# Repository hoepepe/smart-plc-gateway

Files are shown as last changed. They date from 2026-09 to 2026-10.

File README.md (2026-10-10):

# Smart PLC Gateway

Thiết bị giá rẻ đọc dữ liệu từ máy PLC đời cũ — trạng thái máy, lực ép, lực xiết, áp lực khí nén — để tính OEE theo thời gian thực và phát hiện chu kỳ gia công bất thường. Không đụng vào máy: nguồn điện riêng, chỉ đọc, không sửa chương trình PLC.

> Bài dự thi **DENSO Factory Hacks 2026 — đề D1** (Kết nối PLC–IPC giá rẻ để thu dữ liệu).

---

## Bài toán

Theo trả lời của mentor DENSO ngày 21/09/2026:

- DENSO **đã có danh sách tín hiệu** và muốn lấy dữ liệu **trực tiếp từ PLC**
- Hiện dữ liệu PLC đời cũ được lấy **bằng tay qua thẻ nhớ**, và máy cũ **chưa được đưa lên hệ thống giám sát**
- Bộ mở rộng truyền thông cho PLC tốn **khoảng 30 triệu mỗi máy**, chưa tính công và layout
- Ba dòng PLC đang dùng nhiều: **Keyence KV-8000**, **Omron CJ2M-CPU33 và CPM2C**, **Mitsubishi Q10UDEHCPU**
- Điều kiện gia công cần thu: áp lực khí nén, chiều cao, tải trọng, lực ép, lực xiết
- Trạng thái máy: dừng, chuẩn bị vận hành, auto running, đang làm việc, hoàn thành, báo lỗi
- Thiết bị thêm vào phải dùng **nguồn ngoài**, và nên **đi dây** trước để ổn định

Gateway đọc các thanh ghi đó theo giao thức gốc của từng hãng, rồi làm hai việc:
1. **Trạng thái máy → OEE**: độ sẵn sàng, hiệu suất, chất lượng, và nguyên nhân dừng máy xếp theo thời gian mất
2. **Chu kỳ gia công → cảnh báo chất lượng**: chu kỳ ép hoặc siết có hình dạng lạ thường đi kèm chi tiết lỗi

---

## Cấu trúc

```
src/                     Giao diện (React + TypeScript + Vite)
  App.tsx                Điều phối mô phỏng, MQTT và bốn màn hình
  data/machines.ts       Cấu hình 4 máy — PLC, giao thức, thanh ghi, mã lỗi
  data/cycles.json       Tham số mô hình, xuất từ ml/cycles.py
  utils/detector.ts      Khoảng cách Mahalanobis — đúng mô hình đã đánh giá
  utils/oee.ts           OEE = sẵn sàng × hiệu suất × chất lượng
  utils/sim.ts           Mô phỏng vận hành khi chưa có PLC thật
  utils/mqtt.ts          Nối broker, tự về chế độ mô phỏng sau 3 giây
  components/            MonitorTab, OeeTab, DetectionTab, ConnectTab

ml/
  cycles.py              Sinh chu kỳ gia công, huấn luyện và đánh giá, xuất cycles.json
  gateway_sim.py         Giả lập gateway, phát MQTT đúng schema của gateway thật
  legacy_nhan_dien_tin_hieu/   Hướng cũ: AI đoán dây — xem README trong đó

edge/                    AI tự học tại chỗ: runtime nhiều máy, học → duyệt → giám sát, phiên bản, phản hồi
  runtime.py             python -m edge.runtime — đọc PLC/mô phỏng, chấm điểm, MQTT gw/{gw}/...
  learner.py detector.py quality.py store.py config.py sources.py

backend/
  main.py                Nhận MQTT → SQLite → REST API, tính OEE và nguyên nhân dừng máy
```

## Luồng dữ liệu

```
PLC (Keyence / Omron / Mitsubishi)
   │  giao thức gốc của hãng, CHỈ ĐỌC
   ▼
Gateway ── tính đặc trưng chu kỳ, chấm điểm bất thường tại chỗ
   │  MQTT  gw/01/m/{máy}/state   gw/01/m/{máy}/cycle
   ▼
Broker MQTT (Mosquitto, trong mạng nội bộ)
   ├── WebSocket 9001 ──► giao diện
   └── TCP 1883 ────────► backend/main.py ──► SQLite ──► REST API :8000
```

---

## Chạy thử

### Giao diện

```bash
npm install
npm run dev
```

Mở `http://localhost:3000`. Không có broker thì giao diện tự chạy chế độ mô phỏng.

### Mô hình phát hiện chu kỳ bất thường

```bash
cd ml
pip install numpy scikit-learn
python cycles.py
cp cycles.json ../src/data/cycles.json
```

### Chạy đủ chuỗi: broker → gateway giả lập → máy chủ → giao diện

Cài Mosquitto, thêm vào `mosquitto.conf` — **phải bật cả cổng WebSocket**, nếu không trình duyệt không nối được:

```
listener 1883
protocol mqtt

listener 9001
protocol websockets

allow_anonymous true
```

Rồi mở ba cửa sổ dòng lệnh:

```bash
mosquitto -c mosquitto.conf                     # 1. broker
cd backend && pip install -r requirements.txt && python main.py   # 2. máy chủ
cd ml && pip install paho-mqtt && python gateway_sim.py            # 3. gateway giả lập
```

Mở giao diện: góc trên đổi thành **Đã nối gateway**. API máy chủ xem tại `http://localhost:8000/docs`.

| Endpoint | Công dụng |
|---|---|
| `GET /api/health` | Máy chủ sống chưa, đã nối MQTT chưa, đã nhận bao nhiêu bản tin |
| `GET /api/machines` | Trạng thái hiện tại và OEE từng máy |
| `GET /api/machines/{id}/states` | Lịch sử trạng thái |
| `GET /api/machines/{id}/cycles` | Chu kỳ gần đây, lọc được chu kỳ bất thường |
| `GET /api/machines/{id}/oee` | OEE một máy |
| `GET /api/stops` | Nguyên nhân dừng máy, xếp theo thời gian mất |

### AI tự học tại chỗ cho từng máy (tab "Máy và AI tự học")

Mỗi máy tự học chuẩn bình thường của chính nó ngay trên gateway, kỹ sư duyệt rồi mới giám sát, bấm phản hồi trên từng cảnh báo để AI học tiếp. Chi tiết: [docs/HuongDan_AI_TuHoc.md](docs/HuongDan_AI_TuHoc.md).

```bash
pip install -r edge/requirements.txt
python -m edge.runtime --demo                      # 4 máy mô phỏng (ép, siết, CNC, khí nén)
python -m edge.runtime --add-plc 192.168.1.39:3000 # PLC Mitsubishi thật, chỉ đọc
npm run dev                                         # mở tab "Máy và AI tự học"
python -m pytest tests/test_edge.py                 # 6 bài kiểm thử vòng đời
```

---

## Kết quả đo được

Đo trên chu kỳ **mô phỏng**, tách theo ca làm việc: 20 ca để học, 6 ca để chọn ngưỡng, 6 ca để kiểm tra — không ca nào dùng chung. Chỉ học trên chu kỳ bình thường, vì nhà máy có rất ít dữ liệu lỗi.

| Đại lượng | Bắt lỗi trung bình | Báo động giả |
|---|---|---|
| Lực ép | 99,4% | 0,7% |
| Lực xiết | 100% | 0,7% |
| Áp lực khí nén | 70,6% | 0% |

**Chỗ còn yếu:** van kẹt chỉ bắt được 33%, nguồn khí yếu 78%. Giao diện ghi rõ giả thuyết nguyên nhân và hướng sửa cho từng dạng.

**Vì sao chọn khoảng cách Mahalanobis thay vì Isolation Forest:** trên 9 dạng lỗi, Mahalanobis bắt tốt hơn ở 5 dạng, ngang ở 2, kém ở 2. Nó chỉ cần một vector và một ma trận 9×9 nên chạy được trên ESP32, và chỉ ra được đặc trưng nào lệch — kỹ sư biết vì sao máy bị cảnh báo.

**Chất lượng trong OEE là ước tính** — nó đếm chu kỳ bị gắn cờ, mà chu kỳ bất thường mới là nghi lỗi. Nối kết quả kiểm tra QC sẽ chính xác hơn.

---

## Những điều chưa biết

- **Vì sao cần bộ mở rộng 30 triệu khi cả ba CPU đã có cổng Ethernet?** Nếu cổng đang bận cho HMI, gateway cũng phải thêm phần cứng. Cần hỏi mentor trước khi dùng con số tiết kiệm.
- **Thẻ nhớ được rút bao lâu một lần?** Đây là vế "trước" của phép đo độ trễ dữ liệu.
- **Giao thức và lệnh đọc từng dòng PLC** trong `machines.ts` cần đối chiếu manual của hãng.
- Chưa có PLC thật để thử. Toàn bộ trạng thái máy là mô phỏng.

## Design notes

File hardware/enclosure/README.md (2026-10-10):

# Vỏ hộp Smart PLC Gateway (in 3D)

| File | Dùng để |
|---|---|
| `out/gateway_base.stl` | Đế hộp — in thẳng, miệng hộp hướng lên, không cần support |
| `out/gateway_lid_print.stl` | Nắp — đã lật sẵn để mặt ngoài nằm trên bàn in |
| `out/gateway_lid.stl` | Nắp ở tư thế lắp (để xem/ghép trong CAD) |
| `out/viewer.html` | Trình xem 3D xoay được (mở bằng trình duyệt, cần mạng để tải Three.js) |
| `gen_enclosure.py` | Mã tạo hình — mọi kích thước nằm ở các bảng đầu file |

Kích thước ngoài 165 × 110 × 60,5 mm (+ 2 tai bắt vít 12 mm hai đầu). Vừa bàn in 220 × 220.

**Trước khi in:** đo module thật bằng thước kẹp, sửa bảng `MODULES`, `CUTS`, `OLED`, rồi chạy
`python gen_enclosure.py && python build_viewer.py`.

Vật tư kèm theo: 4 vít M3×10 tự ren (nắp), 4 vít M2×6 (OLED), 3 ốc siết cáp PG7, jack DC cái bắt panel ren M8,
2 LED 5 mm, (tuỳ chọn) kẹp DIN rail 35 mm bắt 2 vít M3 dưới đáy.

In: PETG (chịu nhiệt tốt hơn PLA trong tủ điện), lớp 0,2 mm, 3 vách, infill 20%.

**Chỗ cho dây dupont (bản demo):** module có header hàn sẵn hướng xuống (ESP32, W5500, RS232, PC817, HW-685)
được kê cao 28 mm để đầu dupont cái (14 mm) và chỗ uốn dây nằm gọn bên dưới. ADS1115 và MPU6050 thường bán
kèm header rời: hàn header **hướng lên**, module kê thấp 6 mm, dây đi phía trên. Đổi trong bảng `MODULES` (DOWN/UP).

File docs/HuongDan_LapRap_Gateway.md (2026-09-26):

# Hướng dẫn lắp ráp Smart PLC Gateway

*Từ linh kiện rời đến thiết bị hoàn chỉnh trong vỏ ray DIN — DENSO Factory Hacks 2026, đề D1*

---

## Đọc trước khi bắt đầu

**Nguyên tắc số một: lắp từng khối, thử từng khối.** Không hàn tất cả rồi mới cắm điện. Mỗi bước dưới đây kết thúc bằng một phép thử — chỉ sang bước sau khi phép thử đạt. Lắp một lèo rồi hỏng thì không biết hỏng ở đâu.

**Ba điều có thể làm cháy linh kiện ngay lập tức:**

1. Nối ESP32 vào LM2596 **trước khi** chỉnh đầu ra về 5V. LM2596 xuất xưởng có thể ra gần bằng điện áp vào — 24V vào chân VIN là ESP32 chết ngay.
2. Đưa điện áp trên 3,3V vào bất kỳ chân GPIO nào của ESP32. Chân GPIO không chịu 5V.
3. Đấu ngược cực nguồn 24V. Luôn đo bằng đồng hồ trước khi cắm.

**Luôn rút nguồn khi đấu dây.** Chỉ cắm lại khi đã kiểm tra xong.

---

## Phần 1 — Linh kiện

### Linh kiện chính (tổng khoảng 770.000đ)

| # | Linh kiện | Số lượng | Vai trò | Giá |
|---|---|---|---|---|
| 1 | ESP32 DevKit V1 (38 chân) | 1 | Bộ xử lý | 100.000 |
| 2 | Module Ethernet W5500 | 1 | Nối cổng Ethernet của PLC | 90.000 |
| 3 | Module MAX485 | 1 | Cổng RS485 (Keyence KV-8000) | 30.000 |
| 4 | Module MAX3232 | 1 | Cổng RS-232C (Omron CPM2C) | 25.000 |
| 5 | Module ADS1115 | 1 | Đọc tín hiệu analog | 70.000 |
| 6 | Module hạ áp 0–10V → 0–3,3V | 1 | Chuẩn hóa tín hiệu 0–10V | 50.000 |
| 7 | Điện trở **150Ω, sai số 0,1%** | 2 | Đọc tín hiệu 4–20mA | 10.000 |
| 8 | Module PC817 cách ly 4 kênh | 1 | Đọc cờ trạng thái 24V | 40.000 |
| 9 | Adapter 24V DC, 2A | 1 | Nguồn riêng, không lấy từ máy | 120.000 |
| 10 | Module LM2596 (hạ áp chỉnh được) | 1 | 24V → 5V | 30.000 |
| 11 | OLED 0,96" SSD1306 I2C | 1 | Hiện trạng thái tại chỗ | 45.000 |
| 12 | Vỏ ray DIN, domino, PCB lỗ, dây, jack DC | 1 bộ | Đóng gói | 160.000 |

### Linh kiện phụ (thường có sẵn hoặc vài nghìn đồng)

- Điện trở 10kΩ và 20kΩ — cầu chia áp cho chân RO của MAX485
- Header cái 2,54mm — cắm module lên PCB, tháo ra được khi hỏng
- Dây cáp mạng RJ45 ngắn
- Ống co nhiệt, băng keo cách điện

### Linh kiện chỉ dùng khi demo trên bàn

Biến trở 10kΩ, nút nhấn, MPU6050 — tạo tín hiệu giả khi chưa có máy thật. Không nằm trong thiết bị cuối.

### Dụng cụ

- Mỏ hàn (khuyên dùng loại chỉnh nhiệt), thiếc hàn có nhựa thông
- **Đồng hồ vạn năng** — bắt buộc, dùng ở gần như mọi bước
- Kìm tuốt dây, kìm cắt, tua vít nhỏ đầu dẹt và đầu bake
- Breadboard và dây cắm (để thử trước khi hàn)
- Cáp USB micro-B có truyền dữ liệu (không phải cáp chỉ sạc)

---

## ⚠️ Ba chỗ BOM cũ bị sai — đã sửa trong bảng trên

Nếu Đạt đã mua theo danh sách cũ, cần điều chỉnh:

**1. Điện trở 4–20mA phải là 150Ω, không phải 250Ω.**
Dòng 20mA qua 250Ω tạo ra 5V, trong khi ADS1115 cấp 3,3V chỉ chịu tối đa khoảng 3,6V ở đầu vào. Với 150Ω: 4mA → 0,6V, 20mA → 3,0V, nằm gọn trong dải. *Đây là lỗi trong lời khuyên trước đó của mình.*

**2. MAX485 cần cầu chia áp ở chân RO.**
MAX485 chạy ở 5V nên chân RO xuất ra khoảng 5V — đưa thẳng vào ESP32 sẽ hỏng chân. Thêm cầu chia 10kΩ/20kΩ hạ về 3,3V. Nếu mua mới, chọn **MAX3485** (bản 3,3V) thì không cần cầu chia.

**3. Omron CPM2C cần MAX3232, không phải MAX485.**
CPM2C dùng cổng RS-232C. RS-232 dùng mức điện áp khoảng ±12V, hoàn toàn khác RS-485. MAX485 không nói chuyện được với RS-232. Cần mua thêm module MAX3232 (khoảng 25.000đ). *Cũng là lỗi trong lời khuyên trước đó.*

---

## Phần 2 — Sơ đồ tổng quát

```
                    ┌─────────────────────────────────────────┐
  Adapter 24V ──────┤ LM2596 ──5V──┬── ESP32 (VIN)             │
                    │              └── MAX485 (VCC)            │
                    │                                          │
                    │  ESP32 3V3 ──┬── W5500                   │
                    │              ├── ADS1115                 │
                    │              ├── OLED                    │
                    │              ├── MAX3232                 │
                    │              └── PC817 (phía ESP32)      │
                    │                                          │
   PLC Ethernet ────┤ W5500 ──SPI──── ESP32                    │
   PLC RS485 ───────┤ MAX485 ─UART2── ESP32                    │
   PLC RS-232C ─────┤ MAX3232 ─UART1─ ESP32                    │
   Cảm biến 0–10V ──┤ Hạ áp ──┐                                │
   Cảm biến 4–20mA ─┤ 150Ω ───┼─ ADS1115 ─I2C── ESP32          │
   Cờ trạng thái 24V┤ PC817 (cách ly) ──── ESP32 GPIO          │
                    └─────────────────────────────────────────┘
```

### Bảng gán chân ESP32 — dán lên bàn làm việc

| Chân ESP32 | Nối tới | Ghi chú |
|---|---|---|
| VIN | LM2596 OUT+ (5V) | Chỉ cấp 5V |
| GND | GND chung | Trừ phía hiện trường của PC817 |
| 3V3 | VCC các module 3,3V | |
| GPIO 21 | SDA — ADS1115 và OLED | Dùng chung bus I2C |
| GPIO 22 | SCL — ADS1115 và OLED | |
| GPIO 18 | W5500 SCK | SPI |
| GPIO 19 | W5500 MISO | |
| GPIO 23 | W5500 MOSI | |
| GPIO 5 | W5500 CS | |
| GPIO 26 | W5500 RST | Không bắt buộc |
| GPIO 17 | MAX485 DI | UART2 TX |
| GPIO 16 | MAX485 RO **qua cầu chia áp** | UART2 RX |
| GPIO 25 | MAX485 DE + RE (nối chung) | Chọn chiều truyền |
| GPIO 32 | MAX3232 T1IN | UART1 TX |
| GPIO 33 | MAX3232 R1OUT | UART1 RX |
| GPIO 34, 35, 36, 39 | 4 đầu ra PC817 | Chân chỉ-nhập, không có pull-up trong |

**Không dùng** GPIO 0, 2, 12, 15 — đây là chân quyết định chế độ khởi động của ESP32, nối linh kiện vào dễ làm chip không boot được.

### Địa chỉ I2C

| Thiết bị | Địa chỉ | Cách đặt |
|---|---|---|
| ADS1115 | 0x48 | Chân ADDR nối GND |
| OLED SSD1306 | 0x3C | Mặc định |

Hai địa chỉ khác nhau nên dùng chung một bus được.

---

## Phần 3 — Lắp từng khối trên breadboard

### Bước 1: Khối nguồn

**Chưa cắm ESP32 vào ở bước này.**

1. Đấu adapter 24V vào LM2596: dây dương vào `IN+`, dây âm vào `IN-`. Dùng jack DC cái để sau này tháo ra dễ.
2. Cắm adapter.
3. Đặt đồng hồ ở thang DC 20V, đo giữa `OUT+` và `OUT-`.
4. Vặn biến trở trên LM2596 (thường là con ốc nhỏ màu xanh dương) cho đến khi đồng hồ chỉ **5,0V**. Vặn nhiều vòng mới thấy thay đổi — bình thường.
5. Rút adapter, cắm lại, đo lần nữa cho chắc vẫn là 5,0V.

**Kiểm tra đạt:** đầu ra ổn định 4,9–5,1V qua nhiều lần cắm rút.

> Nếu không chỉnh được xuống dưới vài vôn: LM2596 có thể là bản đầu ra cố định. Kiểm tra lại loại module.

### Bước 2: ESP32 chạy một mình

1. Cắm ESP32 vào máy tính bằng cáp USB (chưa nối LM2596).
2. Cài Arduino IDE, thêm board ESP32 (Boards Manager → tìm "esp32" của Espressif).
3. Chọn board **"ESP32 Dev Module"**, nạp chương trình thử:

```cpp
void setup() {
  Serial.begin(115200);
  pinMode(2, OUTPUT);  // LED xanh trên board
}
void loop() {
  digitalWrite(2, !digitalRead(2));
  Serial.println("ESP32 dang chay");
  delay(500);
}
```

**Kiểm tra đạt:** LED trên board nhấp nháy, Serial Monitor in ra dòng chữ.

> Không nạp được: giữ nút **BOOT** trên board khi IDE hiện "Connecting...". Vẫn không được: đổi cáp USB — nhiều cáp chỉ sạc, không truyền dữ liệu.

### Bước 3: Cấp nguồn ESP32 từ LM2596

1. Rút USB. Rút adapter.
2. Nối `OUT+` của LM2596 → chân **VIN** của ESP32. `OUT-` → **GND**.
3. Cắm adapter. LED nguồn trên ESP32 phải sáng, LED chương trình nhấp nháy như bước 2.
4. Đo chân **3V3** của ESP32 so với GND: phải ra khoảng 3,3V.

**Kiểm tra đạt:** ESP32 chạy bằng nguồn 24V qua LM2596, chân 3V3 đúng 3,3V.

> **Lưu ý khi nạp code sau này:** rút dây VIN khỏi LM2596 trước khi cắm USB. Tránh cấp hai nguồn 5V cùng lúc vào một board — nhiều bản ESP32 giá rẻ không có diode chống ngược.

### Bước 4: Bus I2C — OLED trước, ADS1115 sau

**4a. OLED**

| OLED | ESP32 |
|---|---|
| VCC | 3V3 |
| GND | GND |
| SDA | GPIO 21 |
| SCL | GPIO 22 |

Nạp chương trình quét I2C:

```cpp
#include <Wire.h>
void setup() {
  Serial.begin(115200);
  Wire.begin(21, 22);
  for (byte a = 1; a < 127; a++) {
    Wire.beginTransmission(a);
    if (Wire.endTransmission() == 0) Serial.printf("Tim thay: 0x%02X\n", a);
  }
}
void loop() {}
```

**Kiểm tra đạt:** in ra `0x3C`.

**4b. Thêm ADS1115 vào cùng bus**

| ADS1115 | ESP32 |
|---|---|
| VDD | 3V3 |
| GND | GND |
| SDA | GPIO 21 (chung với OLED) |
| SCL | GPIO 22 (chung với OLED) |
| ADDR | GND |

Chạy lại chương trình quét.

**Kiểm tra đạt:** in ra **cả hai** `0x3C` và `0x48`. Thiếu cái nào thì kiểm tra lại dây cái đó.

### Bước 5: Đầu vào analog

Làm theo thứ tự từ an toàn đến nguy hiểm dần.

**5a. Thử bằng biến trở (an toàn nhất)**

Biến trở 10kΩ: một đầu vào 3V3, một đầu vào GND, chân giữa vào `A0` của ADS1115. Cài thư viện **Adafruit ADS1X15**, đọc kênh 0 rồi vặn biến trở.

**Kiểm tra đạt:** giá trị đọc thay đổi mượt từ 0 đến khoảng 3,3V theo vòng vặn.

**5b. Tín hiệu 0–10V**

Tín hiệu 0–10V **không bao giờ** được đưa thẳng vào ADS1115. Luôn đi qua module hạ áp:

```
Cảm biến 0–10V ──► [Module hạ áp] ──► 0–3,3V ──► ADS1115 A1
```

Trước khi nối vào ADS1115: cấp 10V vào đầu vào module, đo đầu ra bằng đồng hồ, phải **không quá 3,3V**.

**5c. Tín hiệu 4–20mA**

Điện trở 150Ω mắc nối tiếp trong vòng dòng, đo điện áp rơi trên nó:

```
+24V ──► Cảm biến 4–20mA ──► ┬── ADS1115 A2
                              │
                           [150Ω]
                              │
                             GND
```

Dòng 4mA cho 0,6V, 20mA cho 3,0V. Phần mềm đổi ngược: `dong_mA = dien_ap / 150 * 1000`.

> Cách mắc này nối đất của vòng cảm biến với đất của gateway — chấp nhận được khi demo. Khi lắp trong nhà máy, cân nhắc bộ cách ly tín hiệu analog để tránh vòng lặp đất.

### Bước 6: Đầu vào số 24V qua PC817 — điểm cách ly quan trọng nhất

Module PC817 có **hai phía tách biệt về điện**. Đây là toàn bộ lý do dùng nó.

| Phía hiện trường (máy) | Phía ESP32 |
|---|---|
| IN1–IN4: tín hiệu 24V từ máy | OUT1–OUT4 → GPIO 34, 35, 36, 39 |
| GND hiện trường: đất của tín hiệu 24V | VCC → 3V3, GND → GND của ESP32 |

**Tuyệt đối không nối GND hiện trường với GND của ESP32.** Nối vào là mất cách ly, và sự cố điện phía máy có thể truyền sang gateway.

Kiểm tra module trước khi dùng: xem điện trở ở phía đầu vào có phù hợp mức 24V không (module ghi 12–24V là được). Loại chỉ ghi 3,3–5V dùng với 24V sẽ cháy LED bên trong.

**Kiểm tra đạt:** dùng adapter 24V riêng và một nút nhấn làm "cờ trạng thái giả". Nhấn nút, GPIO tương ứng đổi mức; nhả ra, đổi lại.

### Bước 7: Ethernet W5500

| W5500 | ESP32 |
|---|---|
| VCC | 3V3 (kiểm tra module của bạn — một số loại có chân 5V riêng) |
| GND | GND |
| SCK | GPIO 18 |
| MISO | GPIO 19 |
| MOSI | GPIO 23 |
| CS (hoặc SS/SCS) | GPIO 5 |
| RST | GPIO 26 |

Cắm dây mạng từ W5500 vào router hoặc thẳng vào laptop. Dùng thư viện **Ethernet** của Arduino, gọi `Ethernet.init(5)` trước `Ethernet.begin()`.

**Kiểm tra đạt:** ESP32 nhận được địa chỉ IP (in ra Serial), và từ máy tính `ping` được tới địa chỉ đó.

> Tắt WiFi trong firmware (`WiFi.mode(WIFI_OFF)`). Vừa đúng khuyến nghị đi dây của DENSO, vừa giảm tải cho bộ ổn áp 3,3V trên ESP32 đang phải nuôi cả W5500.

Sau khi ping được, thử gửi một bản tin MQTT tới broker Mosquitto trên laptop bằng thư viện **PubSubClient**, topic `gw/01/status`. Mở dashboard, thấy nhận được là đạt.

### Bước 8: Cổng serial — RS485 và RS-232C

**8a. MAX485 cho Keyence KV-8000**

| MAX485 | ESP32 |
|---|---|
| VCC | 5V (từ LM2596) |
| GND | GND |
| DI | GPIO 17 |
| RO | GPIO 16 **qua cầu chia áp** |
| DE + RE | Nối chung với nhau → GPIO 25 |
| A, B | Nối vào cổng RS485 của PLC |

Cầu chia áp cho chân RO — **bắt buộc**:

```
MAX485 RO ──[10kΩ]──┬──► GPIO 16
                    │
                 [20kΩ]
                    │
                   GND
```

Trước khi nối GPIO 16: cấp nguồn, đo điểm giữa cầu chia khi đường truyền rảnh — phải khoảng **3,3V, không phải 5V**.

**8b. MAX3232 cho Omron CPM2C**

| MAX3232 | ESP32 |
|---|---|
| VCC | 3V3 |
| GND | GND |
| T1IN (TXD) | GPIO 32 |
| R1OUT (RXD) | GPIO 33 |
| Cổng DB9 | Nối vào cổng RS-232C của PLC |

MAX3232 chạy tốt ở 3,3V nên không cần cầu chia.

**Kiểm tra đạt (cả hai):** thử vòng lặp — nối chân phát với chân nhận ở phía cổng ra (A với B qua một module MAX485 thứ hai, hoặc chân 2 với chân 3 của DB9), gửi một chuỗi, nhận lại đúng chuỗi đó.

### Bước 9: OLED hiển thị trạng thái

Cài thư viện **Adafruit SSD1306** và **Adafruit GFX**. Hiện tối thiểu: địa chỉ IP, trạng thái kết nối MQTT, trạng thái máy đang đọc.

Cập nhật màn hình **mỗi 500ms trở lên**, không cập nhật liên tục — OLED dùng chung bus I2C với ADS1115, cập nhật dày sẽ chiếm bus và làm chậm việc đọc analog.

---

## Phần 4 — Chuyển từ breadboard sang PCB

Chỉ làm khi **mọi bước ở Phần 3 đều đạt** trên breadboard.

### Bố trí

1. Xếp module lên PCB lỗ trước khi hàn. Đặt LM2596 xa ADS1115 nhất có thể — bộ nguồn xung tạo nhiễu, ADS1115 đo điện áp nhỏ rất nhạy với nhiễu.
2. Hàn **header cái** lên PCB rồi cắm module vào, thay vì hàn chết module. Hỏng module nào thì rút ra thay, không phải tháo mạch.
3. Chia PCB thành hai vùng rõ ràng: vùng hiện trường (đầu vào PC817, domino) và vùng ESP32. Khoảng cách giữa hai vùng ít nhất 5mm — đây là khe cách ly.

### Hàn

- Hàn nguồn trước, kiểm tra điện áp, rồi mới hàn phần còn lại.
- Dây nguồn dùng dây to hơn dây tín hiệu.
- Sau khi hàn xong mỗi khối, **đo thông mạch** giữa 5V và GND, giữa 3V3 và GND — không được chạm nhau (đồng hồ không kêu bíp).

### Kiểm tra sau khi hàn

Lặp lại toàn bộ các phép thử ở Phần 3, theo đúng thứ tự. Mạch trên breadboard chạy được không có nghĩa mạch hàn chạy được.

---

## Phần 5 — Đóng gói vào vỏ ray DIN

1. **Domino đấu dây** gắn ở cạnh dưới vỏ, xếp theo nhóm và dán nhãn:

```
[24V+][24V-] │ [A][B] │ [TX][RX][GND] │ [AI1][AI2][GND] │ [DI1][DI2][DI3][DI4][GND-HT]
  Nguồn      │ RS485  │   RS-232C     │    Analog       │   Cờ trạng thái (cách ly)
```

2. **Cổng RJ45** của W5500 khoét lỗ ra ngoài vỏ, để cắm cáp mạng không phải mở nắp.
3. **OLED** khoét lỗ mặt trước, dán kính hoặc mica mỏng che bụi.
4. Cố định PCB bằng ốc và trụ đồng, không dán keo — để sau này mở ra sửa được.
5. Chừa lỗ thoáng khí gần LM2596 — nó tỏa nhiệt khi hạ từ 24V xuống 5V.

---

## Phần 6 — Kiểm tra cuối cùng

### Kiểm tra điện (chưa cắm vào PLC)

| Phép đo | Giá trị đúng |
|---|---|
| Đầu ra LM2596 | 4,9–5,1V |
| Chân 3V3 của ESP32 | 3,2–3,4V |
| Điểm giữa cầu chia MAX485 | ≤ 3,3V |
| Đầu ra module hạ áp khi vào 10V | ≤ 3,3V |
| GND hiện trường với GND ESP32 | **Hở mạch** (không thông) |

### Kiểm tra chức năng

- [ ] OLED hiện IP và trạng thái
- [ ] Dashboard hiện "MQTT: đã kết nối"
- [ ] Vặn biến trở, giá trị analog trên dashboard thay đổi theo
- [ ] Nhấn nút 24V, cờ trạng thái trên dashboard đổi theo
- [ ] Rút dây mạng rồi cắm lại, gateway tự kết nối lại
- [ ] Chạy liên tục 1 giờ không treo, LM2596 không quá nóng (đặt tay giữ được)

### Kiểm tra với PLC

Chưa có PLC thật: dùng phần mềm giả lập trên laptop.

- **Modbus TCP:** phần mềm giả lập Modbus slave miễn phí
- **Mitsubishi MC protocol:** GX Works2/3 có chế độ mô phỏng (cần bản quyền) hoặc thư viện giả lập mã nguồn mở

Có PLC thật: xin mượn ở lab tự động hóa của khoa.

**Trước khi cắm vào PLC thật lần đầu:** đảm bảo firmware **chỉ có lệnh đọc**, không có lệnh ghi. Đây là cam kết "không đụng vào máy" đã ghi trên dashboard — phải đúng từ lần cắm đầu tiên.

---

## Phần 7 — Xử lý sự cố

| Hiện tượng | Nguyên nhân thường gặp | Cách xử lý |
|---|---|---|
| ESP32 không sáng khi cấp 24V | LM2596 chưa chỉnh về 5V, hoặc đấu ngược cực | Đo lại đầu ra LM2596 |
| ESP32 chạy rồi tự khởi động lại liên tục | Nguồn không đủ, hoặc nối nhầm chân boot (0, 2, 12, 15) | Kiểm tra chân đang dùng; thử adapter mạnh hơn |
| Quét I2C không thấy thiết bị | Đảo SDA/SCL, hoặc dây lỏng | Đổi chỗ hai dây, ấn chặt |
| Đọc analog nhảy lung tung | Nhiễu từ LM2596, hoặc chân analog bỏ trống | Đặt ADS1115 xa LM2596; nối đất các kênh không dùng |
| W5500 không nhận IP | Sai chân CS, hoặc thiếu `Ethernet.init(5)` | Kiểm tra lại dây SPI và lệnh khởi tạo |
| Cổng RS485 không nhận gì | Đảo dây A/B | Đổi chỗ A và B — rất hay gặp |
| RS-232C không nhận gì | Đảo TX/RX, hoặc dùng nhầm MAX485 | TX của bên này nối RX của bên kia; dùng MAX3232 |
| Cờ trạng thái không đổi khi có 24V | Module PC817 là loại 5V, đã cháy LED | Kiểm tra loại module; thay loại 12–24V |

---

## Phân công gợi ý

| Người | Phần |
|---|---|
| Đạt | Phần 1–6: mua, lắp, hàn, đóng gói |
| Tuấn | Firmware các bước 2–9, đặc biệt driver đọc PLC |
| Hưng | Nối firmware với dashboard qua MQTT (bước 7) |

Đạt và Tuấn nên làm song song từ bước 4 trở đi: Đạt lắp xong khối nào, Tuấn viết code thử khối đó ngay.

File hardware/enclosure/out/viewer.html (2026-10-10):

# Vỏ hộp Smart PLC Gateway

UET-BigHero · DENSO Factory Hacks 2026 · bản in 3D v0.3

Nắp Tách nắp Linh kiện Nhãn Tổng thể Vách trái Mặt trước Từ trên

kéo: xoay · cuộn: phóng to · chuột phải: dời

## Kích thước ngoài

165 × 110 × 60.5 mm

Chưa tính 2 tai bắt vít 12 mm hai đầu. Vách 2.5 mm, đáy 3 mm, nắp 2.5 mm có gờ lồng, 4 vít M3. In PETG, đế không cần support.

## Lỗ khoét và kết nối

- Vách tráiRJ4517 × 15Cáp LAN tới switch → PLC và laptop cùng mạng
- Vách tráiDB920 × 12Cáp RS232 tới PLC/thiết bị có cổng nối tiếp
- Vách phảiUSB ESP3213 × 8.5Laptop nạp firmware, xem log
- Vách phảiJack DC 5.5×2.1 bắt ren M8Ø8.2Nguồn 24 V tủ điện
- Mặt trướcỐc siết cáp PG7 — đầu vào sốØ12.6Dây tín hiệu từ máy, ốc siết cáp PG7 (cáp Ø3–6,5)
- Mặt trướcỐc siết cáp PG7 — đầu vào sốØ12.6Dây tín hiệu từ máy, ốc siết cáp PG7 (cáp Ø3–6,5)
- Mặt trướcỐc siết cáp PG7 — cảm biến 4–20 mAØ12.6Dây tín hiệu từ máy, ốc siết cáp PG7 (cáp Ø3–6,5)
- Nắp2 lỗ kim EN / BOOTØ3,2Reset và vào chế độ nạp ESP32 không cần mở nắp
- NắpCửa sổ OLED, 3 LED23 × 13Mã QR mở trang máy; LED nguồn, kết nối PLC, cảnh báo AI (xanh/vàng/đỏ)
- Nắp2 nút OK / NGØ12Công nhân xác nhận cảnh báo AI: NG = đúng là lỗi, OK = báo nhầm

## Linh kiện bên trong

- W550055 × 2855 × 28 × 15, RJ45 HanRun HR911105A, header 2×5 (xác nhận: components101)
- RS23233 × 30MAX3232, DB9 cái (xác nhận) · kích thước PCB phổ biến, đo lại
- PC81740 × 304 kênh, header 5 chân hai đầu · kích thước phổ biến, đo lại
- ADS111528 × 1828 × 17,7 (theo Adafruit) · bản clone có thể khác
- ESP3255 × 28Bản DevKit V1 38 chân, micro-USB · 55 × 28 phổ biến, đo lại
- LM259643 × 2143 × 21 × 14 (xác nhận: Surplustronics)
- MPU605021 × 16GY-521 · 21 × 16 phổ biến, đo lại
- HW68542 × 25Đổi dòng 4–20 mA sang áp · 42 × 25 × 10, nguồn 7–36 V (theo trang bán hàng SCCC), đo lại
- OLED 0.96″27 × 27SSD1306, dày 4,1, vùng hiển thị 21,74 × 11,2 (xác nhận: datasheet module)

Mục ghi "đo lại" là kích thước phổ biến của hàng bán ngoài, chưa đo trên module của nhóm. Đo bằng thước kẹp, sửa bảng MODULES trong gen_enclosure.py, chạy lại hai script là có STL và trang này mới.

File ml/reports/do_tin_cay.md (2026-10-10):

# Độ tin cậy của AI gateway

Tạo bằng `python ml/danh_gia_do_tin_cay.py`. Bộ phát hiện là đúng bản chạy trong gateway (`edge/detector.py`).

**Cách đo** (để con số không tự lừa mình):
- Lúc học **không biết nhãn**: dữ liệu học có lẫn chu kỳ lỗi, giống thực tế.
- Kiểm tra trên **ca / khoảng thời gian chưa từng thấy** khi học.
- Ngưỡng chọn chỉ từ dữ liệu học, không chỉnh theo kết quả kiểm tra.
- So với 2 cách khác trên **cùng dữ liệu**: giới hạn PLC (đỉnh + thời gian nằm trong khoảng cho phép — cách OK/NG phổ biến hiện nay) và Isolation Forest.
- Trong ngoặc là **khoảng tin cậy 95%**.

## 1. Bốn loại máy kiểu DENSO (dữ liệu mô phỏng)

Học 300 chu kỳ qua 5 ca (lẫn ~2% chu kỳ lỗi không ai biết). Kiểm tra 400 chu kỳ bình thường và 100 chu kỳ mỗi loại lỗi, lấy từ 10 ca khác. Lặp 3 lần với hạt giống khác nhau rồi cộng dồn.

### Máy ép

| Cách phát hiện | Báo nhầm | Thiếu chi tiết | Chi tiết lệch vị trí | Ép hai lần | Bắt lỗi chung |
|---|---|---|---|---|---|
| Giới hạn PLC (đỉnh + thời gian) | 1.8% (1–3) | 74.7% (69–79) | 47.0% (41–53) | 0.0% (0–1) | 40.6% (37–44) |
| Isolation Forest | 0.0% (0–0) | 2.7% (1–5) | 15.3% (12–20) | 7.7% (5–11) | 8.6% (7–11) |
| **AI của gateway** | 0.5% (0–1) | 100.0% (99–100) | 100.0% (99–100) | 100.0% (99–100) | 100.0% (100–100) |

### Máy siết bu-lông

| Cách phát hiện | Báo nhầm | Trờn ren | Ren chéo | Không tới lực mục tiêu | Bắt lỗi chung |
|---|---|---|---|---|---|
| Giới hạn PLC (đỉnh + thời gian) | 14.7% (13–17) | 36.7% (31–42) | 8.0% (5–12) | 44.7% (39–50) | 29.8% (27–33) |
| Isolation Forest | 0.0% (0–0) | 53.7% (48–59) | 3.7% (2–6) | 15.0% (11–19) | 24.1% (21–27) |
| **AI của gateway** | 1.2% (1–2) | 100.0% (99–100) | 100.0% (99–100) | 100.0% (99–100) | 100.0% (100–100) |

### Máy CNC

| Cách phát hiện | Báo nhầm | Mòn dao | Gãy dao | Rung | Bắt lỗi chung |
|---|---|---|---|---|---|
| Giới hạn PLC (đỉnh + thời gian) | 0.2% (0–1) | 80.7% (76–85) | 28.7% (24–34) | 36.0% (31–42) | 48.4% (45–52) |
| Isolation Forest | 0.0% (0–0) | 35.3% (30–41) | 17.0% (13–22) | 2.0% (1–4) | 18.1% (16–21) |
| **AI của gateway** | 2.2% (2–3) | 99.3% (98–100) | 99.7% (98–100) | 99.7% (98–100) | 99.6% (99–100) |

### Khí nén

| Cách phát hiện | Báo nhầm | Rò khí | Nguồn khí yếu | Van kẹt | Bắt lỗi chung |
|---|---|---|---|---|---|
| Giới hạn PLC (đỉnh + thời gian) | 13.6% (12–16) | 16.7% (13–21) | 72.0% (67–77) | 16.7% (13–21) | 35.1% (32–38) |
| Isolation Forest | 0.0% (0–0) | 16.3% (13–21) | 78.0% (73–82) | 6.3% (4–10) | 33.6% (31–37) |
| **AI của gateway** | 0.2% (0–1) | 82.7% (78–87) | 96.3% (94–98) | 63.3% (58–69) | 80.8% (78–83) |

## 2. Dữ liệu thật: máy phay CNC trong nhà máy Bosch

Bộ dữ liệu công khai CNC Machining của Bosch (CC BY 4.0): rung động 3 máy phay, 2018–2021, lỗi do kỹ sư gắn nhãn. Tín hiệu đưa qua đúng đường gateway (RMS 100 Hz). Mỗi (máy, nguyên công) một mô hình, học nửa đầu theo thời gian (không biết nhãn), kiểm tra nửa sau.

| Cách chạy | Cách phát hiện | AUC | Báo nhầm | Bắt lỗi |
|---|---|---|---|---|
| Học một lần rồi để nguyên | Giới hạn PLC (đỉnh + thời gian) | 0.44 (0.30–0.59) | 20.0% (17–24) | 11.1% (2–44) |
| Học một lần rồi để nguyên | Isolation Forest | 0.83 (0.70–0.92) | 4.9% (3–7) | 11.1% (2–44) |
| Học một lần rồi để nguyên | **AI của gateway** | 0.74 (0.48–0.93) | 43.9% (40–48) | 77.8% (45–94) |
| Học lại theo phản hồi của kỹ sư | Giới hạn PLC (đỉnh + thời gian) | 0.54 (0.35–0.71) | 11.7% (9–15) | 22.2% (6–55) |
| Học lại theo phản hồi của kỹ sư | Isolation Forest | 0.87 (0.79–0.93) | 5.7% (4–8) | 33.3% (12–65) |
| Học lại theo phản hồi của kỹ sư | **AI của gateway** | 0.90 (0.83–0.96) | 18.6% (15–22) | 77.8% (45–94) |

Kiểm tra trên 494 lần chạy tốt và 9 lần chạy lỗi (chỉ 9 lỗi rơi vào nửa sau, nên khoảng tin cậy của tỉ lệ bắt lỗi rất rộng).

## 3. Chuỗi thật: PLC Mitsubishi Q06UDEHCPU → gateway

Phát lại chu kỳ siết bu-lông thật (PyScrew) vào thanh ghi PLC thật, gateway đọc lại qua MC protocol rồi chấm điểm:
20 chu kỳ, đọc ổn định 99,8 mẫu/giây, **kết luận bình thường/bất thường trùng 100%** với chấm trực tiếp trên dữ liệu gốc, điểm lệch trung vị 6,5%. Điều này chứng minh đường truyền PLC → gateway không làm sai kết luận của AI (không phải chứng minh độ chính xác phát hiện lỗi).

## 4. Dữ liệu thật: siết bu-lông PyScrew (TU Dortmund)

Đã chạy trên máy Tuấn (kịch bản s02, s04); đưa `ml/reports/pyscrew_*.md` vào repo để báo cáo này tự dẫn tới.

## Đọc kết quả

- Máy ép: AI bắt 100% lỗi với 0.5% báo nhầm; giới hạn PLC bắt 41% với 1.8% báo nhầm.
- Máy siết bu-lông: AI bắt 100% lỗi với 1.2% báo nhầm; giới hạn PLC bắt 30% với 14.7% báo nhầm.
- Máy CNC: AI bắt 100% lỗi với 2.2% báo nhầm; giới hạn PLC bắt 48% với 0.2% báo nhầm.
- Khí nén: AI bắt 81% lỗi với 0.2% báo nhầm; giới hạn PLC bắt 35% với 13.6% báo nhầm.
- Isolation Forest dùng tham số mặc định, ngưỡng phân vị 99,5 của dữ liệu học (cùng mục tiêu báo nhầm với AI gateway).
- Dữ liệu thật Bosch: khi có kỹ sư phản hồi, AI gateway có AUC cao nhất (0,90) và bắt 7/9 lỗi, nhưng báo nhầm ~19% — cao hơn Isolation Forest (~6%), dù Isolation Forest chỉ bắt 3/9. Chỉ có 9 lỗi nên chưa kết luận chắc được; báo nhầm 19% là chưa đủ để chạy không cần người duyệt.
- Dữ liệu mô phỏng do nhóm tạo, nên con số cao là cận trên. Dữ liệu thật (Bosch) khó hơn nhiều: máy trôi theo nhiều năm.
- Vì vậy thiết kế giữ con người trong vòng lặp: kỹ sư duyệt mọi chuẩn mới, bấm Báo nhầm / Bình thường mới để AI học lại.

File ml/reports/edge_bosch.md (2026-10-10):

# Bộ phát hiện của gateway trên dữ liệu thật Bosch CNC

Dữ liệu rung máy phay trong nhà máy Bosch (công khai, CC BY 4.0), KHÔNG phải dữ liệu DENSO.
Bộ phát hiện: `edge/detector.py` — đúng bản đang chạy trong gateway (lọc bền vững, ngưỡng p99,5 chọn bằng kiểm định chéo theo khối thời gian, Mahalanobis + MAD).

Mỗi (máy, nguyên công) một mô hình, chu kỳ theo thứ tự thời gian. Chỉ dùng nhóm có ≥ 20 lần chạy để học (bộ phát hiện không học với ít hơn 20). Điểm > 1,0 là cảnh báo.

| Cách chạy | Số mô hình | Test good / lỗi | AUC | Báo nhầm | Bắt lỗi |
|---|---|---|---|---|---|
| A. Qua gateway (RMS 100 Hz) · Cách cũ: học trên good đã biết nhãn | 20 | 474 / 9 | 0.722 | 45.6% | 77.8% |
| A. Qua gateway (RMS 100 Hz) · Như thật: học 50% đầu, không biết nhãn | 21 | 494 / 9 | 0.742 | 43.9% | 77.8% |
| A. Qua gateway (RMS 100 Hz) · Như thật + học lại mỗi 10 lần chạy | 21 | 494 / 9 | 0.741 | 44.5% | 77.8% |
| A. Qua gateway (RMS 100 Hz) · Như thật + học lại + kỹ sư bấm Báo nhầm | 21 | 494 / 9 | 0.733 | 39.7% | 77.8% |
| B. Đầy đủ (rung 2 kHz) · Cách cũ: học trên good đã biết nhãn | 20 | 474 / 9 | 0.568 | 62.7% | 77.8% |
| B. Đầy đủ (rung 2 kHz) · Như thật: học 50% đầu, không biết nhãn | 21 | 494 / 9 | 0.592 | 60.9% | 66.7% |
| B. Đầy đủ (rung 2 kHz) · Như thật + học lại mỗi 10 lần chạy | 21 | 494 / 9 | 0.592 | 60.9% | 66.7% |
| B. Đầy đủ (rung 2 kHz) · Như thật + học lại + kỹ sư bấm Báo nhầm | 21 | 494 / 9 | 0.587 | 50.8% | 55.6% |

Ở cách "như thật" (bộ A), 27 lần chạy lỗi lẫn vào dữ liệu học mà không ai biết; bộ lọc bền vững tự bỏ 77 lần chạy, trong đó 27 là lỗi thật.

## Theo máy (bộ A, như thật)

| Máy | Lần chạy good test | Báo nhầm thật | Báo nhầm ước tính lúc học (trung bình) | Lỗi test | Bắt được |
|---|---|---|---|---|---|
| M01 | 87 | 12.6% | 6.6% | 2 | 100% |
| M02 | 247 | 74.1% | 7.7% | 1 | 100% |
| M03 | 160 | 14.4% | 8.2% | 6 | 67% |

Đọc kết quả (nói thật):
- **Bộ phát hiện hiện tại CHƯA đáng tin trên dữ liệu này.** Báo nhầm khoảng 40%, chủ yếu do máy M02 — máy này trôi mạnh theo thời gian (báo cáo cũ cũng thấy M02 báo nhầm 33,6%).
- Mỗi nguyên công chỉ có 20–28 lần chạy để học, rải trong nhiều năm. Gateway được thiết kế học 300 chu kỳ liên tiếp trong một ca rồi học lại định kỳ — dữ liệu Bosch không cho kiểm chứng đúng điều kiện đó.
- "Báo nhầm ước tính" lúc học (5–11%) đã cao hơn mục tiêu 0,5–1%, tức dashboard sẽ báo cho kỹ sư là chuẩn chưa ổn. Nhưng nó vẫn thấp hơn báo nhầm thật khi máy trôi nhiều năm — con số ước tính không thay được thời gian chạy thử.
- Học lại định kỳ chỉ trên chu kỳ không bị cảnh báo gần như không giúp: khi máy trôi, hầu hết chu kỳ đều bị cảnh báo nên không có gì để học. Phải có kỹ sư bấm "Báo nhầm" / "Bình thường mới" thì mới đỡ (≈ 40% thay vì 44%).
- Chỉ có 9 lần chạy lỗi rơi vào nửa sau, quá ít để nói chắc về tỉ lệ bắt lỗi.
- Số mô hình và cách chọn ngưỡng khác báo cáo cũ (bosch_cnc.md), nên hai báo cáo không so trực tiếp được.

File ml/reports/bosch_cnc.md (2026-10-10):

# Kết quả kiểm chứng trên Bosch CNC Machining

Dữ liệu rung máy phay trong nhà máy Bosch (công khai, CC BY 4.0), KHÔNG phải dữ liệu DENSO.

- 1702 lần chạy nguyên công, 70 lần lỗi thật (gán nhãn thủ công).
- Mỗi (máy, nguyên công) một mô hình, train trên 60% lần chạy good sớm nhất; kiểm tra trên phần good muộn hơn + toàn bộ bad.
- Ngưỡng chung: phân vị 99 của điểm leave-one-out trên tập train (đã chuẩn hoá theo từng nguyên công).

## Kết quả chính (mỗi máy × nguyên công một mô hình)

Hai cách chấm điểm: **Mahalanobis** (đám mây nhiều chiều) và **MAD** (lệch xa nhất theo từng đặc trưng, ít tham số hơn — hợp khi chỉ có vài chục chu kỳ bình thường). Ba ngưỡng, đều lấy từ tập train (phân vị 99 / 95 / 90 của điểm leave-one-out) — không nhìn tập kiểm tra.

| Bộ đặc trưng | Chấm điểm | AUC | Ngưỡng p99: báo nhầm / bắt lỗi | p95 | p90 |
|---|---|---|---|---|---|
| A. Qua gateway (RMS 100 Hz) | Mahalanobis | 0.715 | 2.6% / 0.0% | 9.9% / 25.7% | 17.7% / 42.9% |
| A. Qua gateway (RMS 100 Hz) | MAD | 0.873 | 3.0% / 7.1% | 13.5% / 80.0% | 22.9% / 87.1% |
| B. Đầy đủ (rung 2 kHz) | Mahalanobis | 0.772 | 17.7% / 51.4% | 37.0% / 81.4% | 52.8% / 88.6% |
| B. Đầy đủ (rung 2 kHz) | MAD | 0.783 | 3.3% / 8.6% | 16.5% / 48.6% | 30.1% / 71.4% |

Kiểm tra: 665 lần chạy good muộn hơn, 70 lần chạy lỗi, 43 mô hình.

## Theo máy (bộ B, Mahalanobis, ngưỡng p99)

| Máy | Báo nhầm | Bắt được lỗi |
|---|---|---|
| M01 | 6.0% (200) | 61.8% (34) |
| M02 | 33.6% (253) | 55.6% (27) |
| M03 | 9.9% (212) | 0.0% (9) |

## Vì sao không gộp: thí nghiệm phụ

- **Gộp 15 nguyên công vào 1 mô hình mỗi máy** (bộ B): báo nhầm 2.9%, bắt lỗi 14.3%, AUC 0.826.
- **Dùng mô hình của máy này cho máy khác cùng nguyên công**: trung bình 44.3% lần chạy good bị báo nhầm (84 cặp máy × nguyên công).

Đọc kết quả:
- Chuyển mô hình sang máy khác là sai rõ ràng (báo nhầm rất cao) → mỗi máy phải học chuẩn của chính nó.
- Gộp các nguyên công của CÙNG một máy cho AUC không thấp hơn, nhưng ở ngưỡng p99 bắt được ít lỗi hơn hẳn; chưa đủ bằng chứng để nói gộp nguyên công luôn kém — ghi đúng như vậy.
- Mỗi nguyên công chỉ có 8–32 chu kỳ để train và dữ liệu kéo dài 3 năm (trôi theo thời gian), nên báo nhầm trên lần chạy muộn hơn còn cao. Khi triển khai cần thời gian học đủ dài và học lại định kỳ.

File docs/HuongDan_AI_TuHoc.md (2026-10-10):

# AI tự học tại chỗ — hướng dẫn chạy và trình bày

Mỗi máy có một "chuẩn bình thường" riêng, gateway tự học ngay trên máy đó trong ca đầu tiên.
Không cần dataset lịch sử của nhà máy, không cần nhãn lỗi, không cần người làm AI có mặt.
Thuật toán giống nhau cho mọi máy. Chỉ chuẩn bình thường là khác nhau giữa các máy.

## Vòng đời của mỗi máy (và mỗi mã hàng)

```
Khai báo ──▶ Tự học N chu kỳ ──▶ Kỹ sư duyệt ──▶ Giám sát ──▶ (phản hồi, học lại định kỳ) ──▶ Giám sát
```

| Bước | Gateway làm gì | Người làm gì |
|---|---|---|
| Khai báo | — | Tab **Máy và AI tự học → Thêm máy**: chọn mẫu, nhập IP, cổng, thanh ghi tín hiệu, word trạng thái |
| Tự học | Gom N chu kỳ (mặc định 300). **Loại** chu kỳ máy tự báo lỗi và chu kỳ lỗi tín hiệu. Chưa phát cảnh báo AI. | Để máy chạy bình thường, nên qua ≥ 2 ca |
| Huấn luyện | Lọc chu kỳ nghi lỗi lẫn trong dữ liệu học (lệch > 5 MAD), học chuẩn, chọn ngưỡng bằng **kiểm định chéo theo khối thời gian** (mỗi khối ≈ một khoảng ca) để ngưỡng bao được biến động giữa các ca | — |
| Duyệt | Hiện số chu kỳ học, số chu kỳ tự bỏ, báo nhầm ước tính, chấm thử trên chu kỳ mới | Bấm **Kích hoạt giám sát** hoặc **Học lại từ đầu** |
| Giám sát | Mỗi chu kỳ: điểm (1,0 = ngưỡng), 3 đặc trưng lệch nhiều nhất, gợi ý loại lỗi nếu đủ nhãn | Phản hồi trên mỗi cảnh báo |
| Học lại định kỳ | Sau mỗi `retrain_every` chu kỳ: học lại trên chu kỳ gần đây **không bị cảnh báo, không bị đánh dấu lỗi** → bản chờ duyệt, kèm độ dịch chuẩn so với bản đang chạy và **so với bản gốc** | Duyệt / giữ bản cũ. Bản nào cũng giữ lại, **quay về** được |

**Ba nút phản hồi trên mỗi cảnh báo**

- **Đúng là lỗi** (ghi loại lỗi): thành nhãn. Đủ ≥ 10 nhãn, ≥ 2 loại, mỗi loại ≥ 3 thì tự bật tầng phân loại (Random Forest), cảnh báo sau có dòng "AI đoán: …".
- **Báo nhầm**: chu kỳ được đưa vào dữ liệu học lại.
- **Bình thường mới**: chế độ chạy mới hợp lệ. Đủ 10 chu kỳ thì tự tạo bản học lại. Tick "áp cho mọi cảnh báo đang mở" để gắn nhãn cả loạt.

**Mã hàng:** khai báo thanh ghi mã hàng thì mỗi mã hàng tự học chuẩn riêng. Mã hàng chưa từng chạy sẽ tự vào chế độ học.

**Lỗi tín hiệu khác lỗi máy:** tín hiệu đứng im, vượt dải vật lý, hay đọc PLC bị hụt mẫu thì báo **lỗi tín hiệu**. Những chu kỳ này không được chấm điểm và không được dùng để học.

## Dashboard đổi theo loại máy

PLC không tự cho biết nó điều khiển máy gì: thanh ghi D300 chỉ là một con số. Nên kỹ sư chọn **loại máy một lần**
trong form "Thêm máy". Sau đó dashboard tự nói đúng ngôn ngữ của máy đó. Thuật toán AI vẫn giống nhau cho mọi loại.

| Loại máy | Tín hiệu | Một chu kỳ gọi là | Mã hàng gọi là | Gợi ý loại lỗi khi bấm "Đúng là lỗi" |
|---|---|---|---|---|
| Máy ép (press-fit) | Lực ép (kN) | lần ép | Mã hàng | Thiếu chi tiết, lệch vị trí, ép hai lần… |
| Máy siết bu-lông | Mô-men siết (N·m) | lần siết | Mã bu-lông | Trờn ren, ren chéo, chưa đủ lực… |
| Máy CNC phay / tiện | Tải trục chính (%) | chu kỳ gia công | Chương trình NC | Mòn dao, gãy/mẻ dao, rung (chatter)… |
| Máy hàn điểm | Dòng hàn (kA) | điểm hàn | Chương trình hàn | Thiếu ngấu, bắn tóe, điện cực mòn… |
| Máy ép phun nhựa | Áp suất phun (MPa) | lần phun | Khuôn | Short shot, ba via, co ngót… |
| Cụm khí nén / kiểm tra rò | Áp suất khí (bar) | chu kỳ | Mã hàng | Rò khí, nguồn khí yếu, van kẹt |
| Máy khác | Tín hiệu quá trình | chu kỳ | Mã hàng | (kỹ sư tự gõ) |

Những gì đổi theo loại máy:
- biểu tượng và tên loại trên thẻ máy
- tên tín hiệu và đơn vị
- cách gọi chu kỳ và mã hàng
- tên các đặc trưng trong cảnh báo, ví dụ máy CNC hiện "độ rung tải (chatter)" thay vì "độ gồ ghề"
- danh sách loại lỗi bấm nhanh
- thanh ghi gợi ý trong form

Thêm loại máy mới chỉ cần thêm một mục trong `edge/profiles.py`, không phải sửa giao diện.

**Phân loại lỗi dùng chung giữa các máy cùng loại.** Nhãn "Đúng là lỗi · Mòn dao" gắn trên máy CNC số 1 cũng giúp
máy CNC số 2 đoán loại lỗi, kể cả khi hai máy chạy mức tải khác nhau. Lý do: mỗi chu kỳ lỗi được quy về "lệch bao nhiêu
lần độ lệch thường" so với chuẩn của chính máy đó. Máy khác loại thì không dùng chung.

## Kiểm chứng độ chính xác ngay tại nhà máy

Không cần mua thêm đồ đo. Công nhân kiểm chi tiết bằng cách quen thuộc ở chuyền (nhìn, dưỡng go/no-go,
trạm kiểm tra sẵn có) rồi bấm một nút.

| Ở đâu | Làm gì | Dashboard tính ra |
|---|---|---|
| Nút trên dashboard (quét QR trên OLED → trang của máy) | Đúng là lỗi / Báo nhầm / Bình thường mới trên từng cảnh báo | Cảnh báo đúng = lỗi thật / cảnh báo đã xác nhận |
| **Nút NG / OK trên hộp gateway** | NG = đúng là lỗi, OK = báo nhầm, cho cảnh báo mở gần nhất (15 phút). Không có cảnh báo mà bấm NG → "AI bỏ sót" | như trên |
| "Báo lỗi AI bỏ sót" (dashboard) | Trạm kiểm tra cuối chuyền phát hiện lỗi mà AI không báo → chọn chu kỳ đó | Lỗi AI bắt được = lỗi AI bắt / lỗi đã biết |
| **"Kiểm tra mẫu NG chuẩn"** | Đầu ca bấm Bắt đầu, cho chạy 1–5 chi tiết lỗi chuẩn từ kho mẫu NG. AI phải bắt hết. Các chu kỳ này không tạo cảnh báo, không dùng để học | Lịch sử "AI bắt 3/3 ✓" |

Tất cả nằm trong tab **Máy và AI tự học → chọn máy → ô "Độ chính xác thực tế tại máy"** (hiện khi máy đang giám sát).

**Đèn trên hộp gateway:** xanh = bình thường · vàng = đang học / chờ duyệt / đang kiểm tra mẫu NG ·
đỏ nháy = có cảnh báo AI chưa xác nhận · đỏ sáng liền = mất kết nối PLC. Bấm nút → đèn nháy xác nhận.

Phần cứng: `firmware/nut_xac_nhan/nut_xac_nhan.ino` (nút GPIO32/33, LED GPIO25/27, còi GPIO14), nắp hộp có
2 lỗ nút Ø12 và 3 lỗ LED. Cầu nối USB ↔ MQTT trên laptop:

```
python tools/nut_bam_bridge.py --serial COM5 --machine M01     # có ESP32
python tools/nut_bam_bridge.py --ban-phim --machine SIM-EP1    # chưa có ESP32: gõ n = NG, o = OK
```

**Kết quả kiểm chứng đầy đủ** (so với giới hạn PLC, Isolation Forest, dữ liệu thật Bosch, PLC thật) xem ở tab
**Kiểm chứng AI** trên dashboard, hoặc `ml/reports/do_tin_cay.md`.

## Chạy thử không cần PLC (máy mô phỏng)

```
mosquitto -c mosquitto.conf -v               # hoặc dịch vụ Mosquitto đang chạy sẵn
pip install -r edge/requirements.txt
python -m edge.runtime --demo                 # 4 máy mô phỏng: ép, siết (2 mã bu-lông), CNC (2 chương trình NC), khí nén (tự duyệt)
npm run dev                                   # mở http://localhost:3000 → tab "Máy và AI tự học"
```

Máy mô phỏng chạy nhanh (khoảng 4 chu kỳ/giây), nên xem hết vòng đời học → duyệt → giám sát trong khoảng 1 phút.
Chạy lại từ đầu thì thêm `--fresh` để xoá dữ liệu cũ (`edge_data/edge.db`).

## Chạy với PLC Mitsubishi thật

```
python -m edge.runtime --add-plc 192.168.1.39:3000                          # máy ép, tín hiệu D100
python -m edge.runtime --add-plc 192.168.1.39:3000 --type cnc --signal D100  # cùng PLC nhưng trình bày như máy CNC
```

`--type` nhận: press, torque, cnc, weld, injection, air, generic.

Lệnh này khai báo nhanh máy M01 với cấu hình: tín hiệu theo loại máy (máy ép: D100 × 0,01), word trạng thái M0 (bit 3 = đang làm việc),
mã lỗi D110. Cấu hình khác thì thêm máy từ dashboard. Cổng nhập **số thập phân**, mỗi dòng Open Setting chỉ nhận
một kết nối. Gateway chỉ gửi lệnh **đọc**.

Đã thử với `tools/plc_gia_lap.py` (PLC giả lập MC protocol): runtime kết nối được, cắt chu kỳ theo bit M3,
và loại đúng chu kỳ có máy báo lỗi (M5 + D110).

## MQTT (cho Tuấn và Duy)

| Topic | Nội dung |
|---|---|
| `gw/01/registry` (giữ lại) | danh sách máy + cấu hình + các mẫu |
| `gw/01/m/{máy}/learn` (giữ lại) | chế độ, tiến độ học, mô hình đang chạy / chờ duyệt, phiên bản, 25 cảnh báo gần nhất, trạng thái phân loại |
| `gw/01/m/{máy}/cycle` | mỗi chu kỳ: `y`, `f`, `kind` (learn/preview/score/dq/excluded), `norm`, `score.top`, `alarm_id` |
| `gw/01/m/{máy}/state` | trạng thái máy (giống cầu nối cũ) |
| `gw/01/m/{máy}/andon` (giữ lại) | màu đèn trên hộp gateway `{color, blink, text}` |
| `gw/01/m/{máy}/button` → `button_ack` | nút trên hộp gateway gửi `{"label": "fault"\|"false_alarm"}` |
| `gw/01/cmd` → `gw/01/ack` | lệnh `{id, op, …}`: add_machine, update_machine, remove_machine, approve, reject, relearn, rollback, retrain_now, feedback, set_ai, ng_check_start, ng_check_cancel, report_missed, sim_inject (máy mô phỏng) |

## Nói gì khi trình bày

- *"Lắp vào máy mới, gateway tự học chuẩn bình thường trong một ca. Không cần dữ liệu lịch sử, không cần chuyên gia AI."*
- *"AI không tự âm thầm thay đổi: mỗi lần học lại là một phiên bản, kỹ sư duyệt, sai thì quay về."*
- *"Chúng em theo dõi độ dịch so với chuẩn gốc, nên hao mòn từ từ vẫn lộ ra dù AI học lại định kỳ."*

## Giới hạn hiện tại (nói thật nếu được hỏi)

- Số đo đầy đủ, có so với giới hạn PLC và Isolation Forest, kèm khoảng tin cậy 95%: [ml/reports/do_tin_cay.md](../ml/reports/do_tin_cay.md) (tạo lại bằng `python ml/danh_gia_do_tin_cay.py`).
  - Mô phỏng 4 loại máy (học lẫn 2% lỗi không ai biết, kiểm tra trên 10 ca khác): AI bắt 81–100% lỗi, báo nhầm 0,2–2,2%; giới hạn PLC bắt 30–48%.
  - Dữ liệu thật Bosch CNC: có kỹ sư phản hồi thì AUC 0,90 (0,83–0,96), bắt 7/9 lỗi, nhưng báo nhầm ~19% — chưa đủ để chạy không cần người duyệt.
  - Khí nén còn yếu nhất: van kẹt bắt ~63%.
- Báo nhầm và Bình thường mới: đủ 5 nhãn thì AI tự tạo bản học lại chờ duyệt (không đợi lần học lại định kỳ).
- Chưa tự nhận ra loại máy từ hình dạng tín hiệu; kỹ sư chọn một lần khi thêm máy.
- Các tab cũ (Giám sát máy, OEE, Phát hiện bất thường) vẫn là demo cố định 4 máy. Tab "Máy và AI tự học" là phần tự đổi theo máy.
- Driver mới có Mitsubishi MC 3E. Omron FINS và Keyence chưa làm.
- Ngưỡng phân vị 99,5 → mục tiêu báo nhầm khoảng 0,5–1% mỗi tầng. Con số thật phải đo trên máy thật.

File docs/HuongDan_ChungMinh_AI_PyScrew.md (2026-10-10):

# Chứng minh độ chính xác AI bằng dữ liệu máy thật + PLC thật

Mục tiêu: trả lời câu giám khảo chắc chắn sẽ hỏi — *"AI của các bạn có bắt được lỗi trên máy thật không, hay chỉ trên dữ liệu tự bịa?"*

Ý tưởng: lấy dữ liệu **siết bu-lông công nghiệp thật** có nhãn lỗi (bộ PyScrew, TU Dortmund), cho nó **chạy qua PLC Mitsubishi thật + gateway**, rồi so kết luận của AI với nhãn đúng.

```
PyScrew (máy thật, có nhãn) ─ghi─▶ PLC Q06UDEH ─đọc─▶ ESP32 / laptop ─▶ AI ─▶ so với nhãn đúng
```

## Nói gì khi trình bày (đọc trước)

| Được nói | KHÔNG được nói |
|---|---|
| "AI kiểm chứng trên dữ liệu siết bu-lông công nghiệp công khai, có lỗi thật" | "AI đã chạy trên máy DENSO" |
| "Dữ liệu máy thật đi qua PLC Mitsubishi thật và gateway, AI vẫn chấm đúng X%" | "PLC đo được momen" — PLC chỉ chứa và chuyển dữ liệu |
| Ghi đúng con số script in ra, kể cả loại lỗi bắt kém | Chỉ chọn con số đẹp |

Giấy phép PyScrew: xem trang Zenodo trước khi ghi vào proposal. Thư mục `ml/data/` đã được bỏ khỏi git — không đẩy dữ liệu tải về lên repo.

---

## Phần 1 — Duy: train và đánh giá (laptop có mạng, ~15 phút)

```
cd smart-plc-gateway
git pull
pip install pyscrew numpy scikit-learn
python ml/benchmark_pyscrew.py --scenario s03
```

Lần đầu script tải dữ liệu từ zenodo.org (vài phút). Kết quả:

- `ml/reports/pyscrew_s03.md` — bảng kết quả cho slide
- `ml/models/pyscrew_s03.json` — mô hình để cầu nối dùng
- `ml/data/pyscrew_s03_replay.csv` — 300 chu kỳ kiểm tra (một nửa lỗi) để phát qua PLC

Script so hai bộ đặc trưng:
- **A. Qua PLC** — chỉ một thanh ghi momen, 100 lần/giây: đúng những gì gateway thấy.
- **B. Đầy đủ** — momen + góc ở 833 Hz: trần nếu đọc thêm tín hiệu. Khoảng cách A–B là lý do nên đọc thêm thanh ghi góc khi triển khai thật.

Chạy thêm để có bức tranh đầy đủ:
```
python ml/benchmark_pyscrew.py --scenario s02     # ma sát bề mặt
python ml/benchmark_pyscrew.py --scenario s01     # ren mòn dần: điểm bất thường theo số lần dùng
```
Nếu một kịch bản báo "quá ít lần siết bình thường" thì bỏ qua kịch bản đó.

Gửi Tuấn file `pyscrew_s03_replay.csv` và `pyscrew_s03.json` (qua Drive/Zalo, không qua git).

---

## Phần 2 — Tuấn: thử trên PLC giả lập trước (ở nhà, ~10 phút)

Bốn cửa sổ, đều `cd C:\Users\7560\smart-plc-gateway` trước. Đặt 2 file Duy gửi vào `ml\data\` và `ml\models\`.

1. Mosquitto: `"C:\Program Files\mosquitto\mosquitto.exe" -c mosquitto.conf -v`
2. PLC giả lập ở chế độ **thụ động** (chỉ giữ giá trị được ghi vào):
   ```
   python tools\plc_gia_lap.py --passive
   ```
3. Cầu nối, dùng mô hình PyScrew và ghi log:
   ```
   python tools\plc_to_mqtt.py --plc 127.0.0.1 --plc-port 5000 --model ml\models\pyscrew_s03.json --scale 0.001 --log-csv log_gia_lap.csv
   ```
4. Phát lại (thử 20 chu kỳ trước):
   ```
   python tools\phat_lai_vao_plc.py ml\data\pyscrew_s03_replay.csv --plc 127.0.0.1 --limit 20
   ```

Xong thì Ctrl+C cửa sổ 3, rồi chấm:
```
python tools\danh_gia_qua_plc.py ml\data\pyscrew_s03_replay.csv log_gia_lap.csv --model ml\models\pyscrew_s03.json
```

---

## Phần 3 — Tuấn: chạy trên PLC thật ở lab

### 3.1 Chuẩn bị PLC (GX Works2)

- **Chuyển PLC sang STOP** (công tắc trên CPU hoặc Online → Remote Operation → STOP). Khi STOP, chương trình ladder không chạy nên không ghi đè D100, D102, M0–M15 (ladder sinh dữ liệu của Tuấn đang dùng M0–M5). Đọc/ghi thanh ghi qua Ethernet vẫn hoạt động khi STOP.
- Nếu muốn để RUN: trong *Built-in Ethernet Port Setting* tích ô cho phép ghi khi RUN (dòng có chữ "Enable online change"), nạp lại tham số, và đảm bảo ladder không đụng D100, D102, M0–M15.
- Open Setting giữ như cũ: TCP, MC Protocol, cổng (nhập hex trong GX Works2, dùng số thập phân ở lệnh dưới).

> Chưa thử lệnh ghi trên PLC thật của nhóm. Nếu script báo lỗi khi ghi, chụp màn hình lỗi gửi lại — thường do chưa cho phép ghi hoặc sai cổng.

### 3.2 Chạy (laptop nối thẳng PLC)

Giống Phần 2, chỉ khác: **không chạy** `plc_gia_lap.py`, và thay `127.0.0.1` bằng `192.168.1.39`:

```
python tools\plc_to_mqtt.py --plc 192.168.1.39 --plc-port 5000 --model ml\models\pyscrew_s03.json --scale 0.001 --log-csv log_plc_that.csv
python tools\phat_lai_vao_plc.py ml\data\pyscrew_s03_replay.csv --plc 192.168.1.39 --plc-port 5000
```

300 chu kỳ mất khoảng 15–20 phút. Chấm:
```
python tools\danh_gia_qua_plc.py ml\data\pyscrew_s03_replay.csv log_plc_that.csv --model ml\models\pyscrew_s03.json --out ket_qua_qua_plc.md
```

### 3.3 Qua ESP32 (bước mạnh nhất)

Firmware `gateway_serial` đã gửi D100, D102, D110, M lên USB, nên không cần sửa firmware. Laptop vẫn chạy `phat_lai_vao_plc.py` (ghi vào PLC qua cổng mạng khác hoặc qua switch), còn cầu nối đọc từ ESP32:
```
python tools\plc_to_mqtt.py --serial COM5 --model ml\models\pyscrew_s03.json --scale 0.001 --log-csv log_esp32.csv
```
Lưu ý: ESP32 phải đọc PLC đủ nhanh (≈100 lần/giây). Nếu chậm hơn, điểm qua chuỗi sẽ lệch nhiều so với offline — đó cũng là một số liệu đáng báo cáo.

### 3.4 Quay video bằng chứng

Màn hình chia đôi: GX Works2 *Device Monitor* (D100, D102 nhảy số) + dashboard / cửa sổ cầu nối in "Chu kỳ #… (D102=…) → BẤT THƯỜNG". Kết thúc video bằng bảng của `danh_gia_qua_plc.py`.

---

## Đọc kết quả

`danh_gia_qua_plc.py` in ba thứ:

1. **Thiếu chu kỳ** — bằng 0 nghĩa là đường truyền không mất chu kỳ nào.
2. **Độ lệch điểm qua PLC so với offline** — nhỏ nghĩa là chuỗi thu thập không làm méo dữ liệu. Thử nghiệm trên PLC giả lập: trung vị khoảng 3%.
3. **Bảng gắn cờ và ma trận nhầm lẫn** — đây là độ chính xác của AI trên dữ liệu máy thật sau khi đi qua PLC.

Nhóm "Lỗi ngầm (máy báo OK)" là con số quan trọng nhất cho DENSO: máy siết tự cho là đạt, PLC không báo gì, chỉ AI phát hiện được.

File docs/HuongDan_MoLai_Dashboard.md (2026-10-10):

# Mở lại dashboard và nối đủ chuỗi (dành cho Tuấn)

Dùng khi đã tắt hết và cần bật lại từ đầu. Thư mục dự án: `C:\Users\7560\smart-plc-gateway`.

Chuỗi cần chạy: **PLC (giả hoặc thật) → plc_to_mqtt.py → Mosquitto → Dashboard**.
Mỗi bước dùng **một cửa sổ terminal riêng** (PowerShell hoặc CMD). Không đóng cửa sổ nào khi đang chạy.

## Trước khi bắt đầu: kéo code mới nhất (làm 1 lần)

```
cd C:\Users\7560\smart-plc-gateway
git pull
```

## Cửa sổ 1 — Mosquitto (máy chủ MQTT)

```
cd C:\Users\7560\smart-plc-gateway
"C:\Program Files\mosquitto\mosquitto.exe" -c mosquitto.conf -v
```

- Thấy dòng `Opening ipv4 listen socket on port 1883` và `...port 9001` là đúng.
- Nếu báo cổng 1883 đã bị dùng: Mosquitto đang chạy ngầm dạng service. Mở PowerShell **Run as administrator**, gõ `net stop mosquitto`, rồi chạy lại lệnh trên.

## Cửa sổ 2 — PLC

Chọn **một** trong hai.

**A. PLC giả lập (không cần phòng lab):**
```
cd C:\Users\7560\smart-plc-gateway
python tools\plc_gia_lap.py
```
Thấy `PLC giả lập chờ ở cổng 5000` là được.

**B. PLC thật (ở phòng lab):** không chạy gì ở cửa sổ này. Chỉ cần PLC bật, cắm cáp mạng, laptop đặt IP tĩnh cùng lớp mạng, ví dụ `192.168.1.100`, mask `255.255.255.0`. Kiểm tra bằng `ping 192.168.1.39`. Xem `docs/HuongDan_LapRap_Gateway.md` để biết chi tiết.

## Cửa sổ 3 — Cầu nối PLC → MQTT

**Với PLC giả lập:**
```
cd C:\Users\7560\smart-plc-gateway
python tools\plc_to_mqtt.py --plc 127.0.0.1 --plc-port 5000
```

**Với PLC thật** (cổng là số **thập phân**; GX Works2 nhập hex, ví dụ `1388` hex = `5000` thập phân):
```
python tools\plc_to_mqtt.py --plc 192.168.1.39 --plc-port 5000
```

Thấy terminal in giá trị liên tục là đang đọc được. Thêm `--log-csv cycles_M01.csv` nếu muốn lưu dữ liệu cho Duy.

## Cửa sổ 4 — Dashboard

```
cd C:\Users\7560\smart-plc-gateway
npm install      (chỉ cần lần đầu)
npm run dev
```

Mở trình duyệt vào **http://localhost:3000**.

## Kiểm tra đã nối đúng chưa

- Góc dashboard hiện **"Đã nối gateway"** (nếu hiện "Chế độ mô phỏng" thì chưa nối).
- Máy M01 có số liệu thay đổi liên tục, số chu kỳ tăng dần.
- Chỉ máy M01 lấy dữ liệu từ gateway; các máy khác trên dashboard là dữ liệu mẫu.

## Lỗi thường gặp

| Hiện tượng | Cách xử lý |
|---|---|
| `python` không nhận lệnh | Cài Python 3.14 (không dùng 3.15), tích "Add to PATH" |
| `No module named numpy` / `paho` / `pymcprotocol` | `pip install numpy paho-mqtt pymcprotocol` |
| `unknown slot ID` khi import numpy | Đang dùng Python 3.15, đổi sang 3.14 |
| `mosquitto` không nhận lệnh | Dùng đường dẫn đầy đủ như ở cửa sổ 1 |
| Dashboard vẫn "Chế độ mô phỏng" | Kiểm tra cửa sổ 1 còn chạy và có cổng 9001; tải lại trang (Ctrl+F5) |
| Cầu nối báo lỗi kết nối PLC | PLC giả: cửa sổ 2 đã chạy chưa. PLC thật: ping được IP chưa, cổng thập phân đúng chưa |

## Thứ tự khi tắt

Đóng ngược lại: dashboard → cầu nối → PLC giả → Mosquitto (Ctrl+C ở mỗi cửa sổ).

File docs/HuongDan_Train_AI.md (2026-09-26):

# Hướng dẫn phần AI — cho Duy

*Cập nhật sau trả lời của mentor DENSO ngày 21/09/2026.*

## Việc đã đổi

Bài toán cũ — AI đoán một dây đang đo đại lượng gì — **không còn là trọng tâm**, vì DENSO đã có danh sách tín hiệu. Code cũ giữ ở `ml/legacy_nhan_dien_tin_hieu/`.

Bài toán mới: **phát hiện chu kỳ gia công bất thường** trên lực ép, lực xiết, áp lực khí nén. Chu kỳ lạ thường đi kèm chi tiết lỗi.

Trạng thái máy và OEE **không cần AI** — chỉ là đọc thanh ghi rồi cộng thời gian.

## Chạy ngay, không cần GPU, không cần dữ liệu thật

```bash
cd ml
pip install numpy scikit-learn
python cycles.py
```

Khoảng vài giây. Dữ liệu mô phỏng là **đúng quy định**: dữ liệu thật của DENSO chỉ cấp khi vào Top 10.

## Mô hình đang dùng

Khoảng cách **Mahalanobis** trên 9 đặc trưng mỗi chu kỳ (giá trị đỉnh, đáy, thời điểm đạt đỉnh, mức trung bình, độ dốc tăng, độ gồ ghề, số đỉnh, mức đầu, mức giữa chu kỳ). Isolation Forest được chạy song song để so sánh.

## Ba nguyên tắc — đừng phá

1. **Tách theo ca, không tách ngẫu nhiên.** Các chu kỳ trong cùng một ca rất giống nhau, tách ngẫu nhiên thì con số đẹp giả tạo.
2. **Chỉ học trên chu kỳ bình thường.** Nhà máy có rất ít dữ liệu lỗi — phương pháp phải sống được với điều đó.
3. **Chọn ngưỡng trên ca hiệu chuẩn, không bao giờ nhìn tập kiểm tra.**

## Việc cần làm, theo thứ tự

1. **Sửa hai chỗ yếu.** Van kẹt bắt 33%, nguồn khí yếu 78%. Giả thuyết: van kẹt cần đặc trưng bắt biến thiên nhanh; nguồn khí yếu nên thêm luật ngưỡng áp nền tuyệt đối. Thử từng giả thuyết, đo lại, ghi cả kết quả xấu.
2. **Làm dữ liệu khó hơn.** Thêm biến động giữa các ca, nhiễu điện, chu kỳ bị cắt ngang. Con số 99–100% hiện tại là do dữ liệu dễ.
3. **Thêm chiều cao và tải trọng** — DENSO có nêu nhưng chưa mô phỏng.
4. **Khi có PLC hoặc CSV thật**, thay phần sinh chu kỳ trong `cycles.py` bằng đọc CSV. Phần huấn luyện và đánh giá giữ nguyên.
5. **Việc ngoài AI hợp với Duy nhất:** viết driver đọc Mitsubishi MC protocol bằng Python (thư viện `pymcprotocol`). Đây là mắt xích quyết định dự án có đọc được PLC thật hay không.

Sau mỗi lần sửa: chạy `cycles.py`, copy `cycles.json` sang `src/data/`, mọi con số trên giao diện tự cập nhật.

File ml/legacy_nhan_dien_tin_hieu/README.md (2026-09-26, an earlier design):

# Bản cũ — nhận diện loại tín hiệu

Thư mục này giữ lại hướng tiếp cận ban đầu: AI đoán một dây tín hiệu đang đo đại lượng gì
(nhiệt độ, rung động, bộ đếm, tải động cơ).

**Vì sao không còn là hướng chính:** ngày 21/09/2026 mentor DENSO xác nhận DENSO đã có
danh sách tín hiệu và muốn lấy dữ liệu trực tiếp từ PLC. Bài toán đoán dây không còn
là painpoint.

Vẫn giữ lại vì hai kết quả còn giá trị cho đường tín hiệu analog phụ (DENSO xác nhận vẫn
dùng cả 0–10V và 4–20mA):
- Hai lớp bảo vệ: đấu ngược cực — mô hình bắt 0%, luật kiểm tra dải bắt 100%
- Ngưỡng tin cậy một mình không phát hiện được tín hiệu lạ (8.3%), cần mô hình one-class (100%)

Hướng hiện tại nằm ở `../cycles.py`.

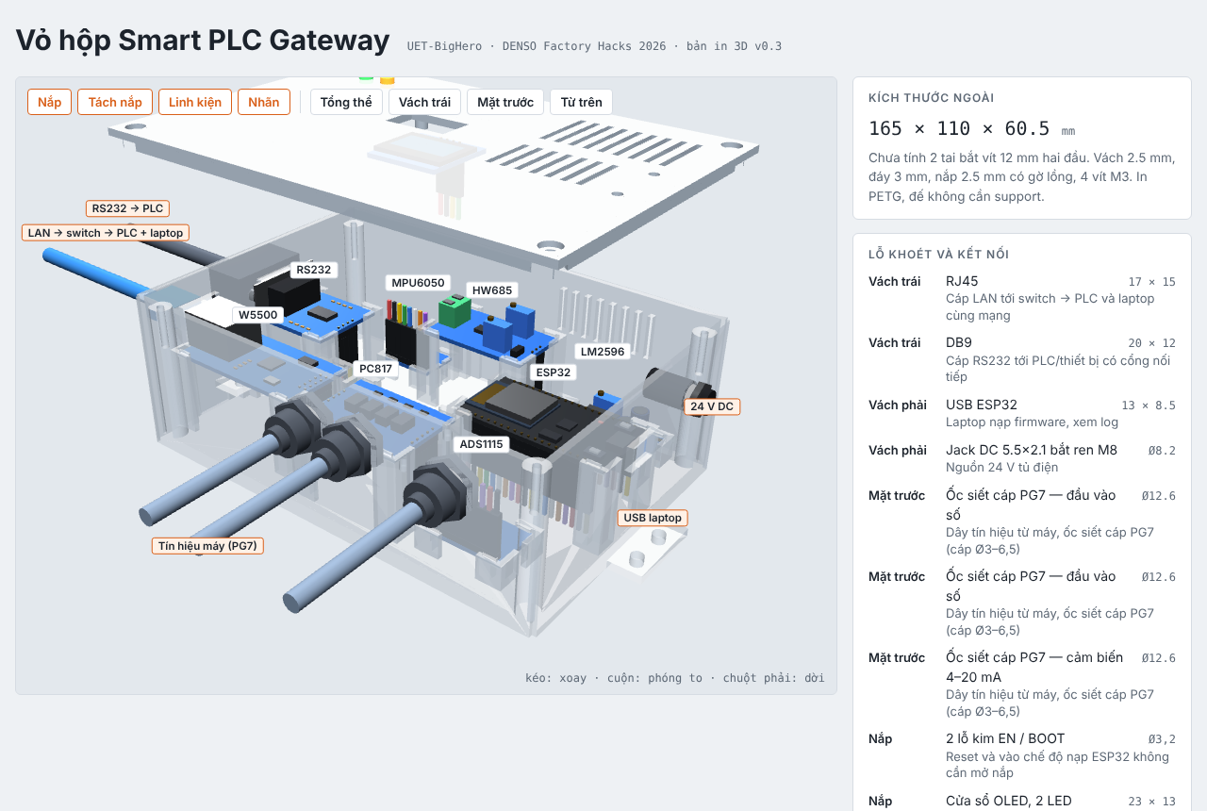
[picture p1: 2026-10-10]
hardware/enclosure/out/anh_xem_truoc.png

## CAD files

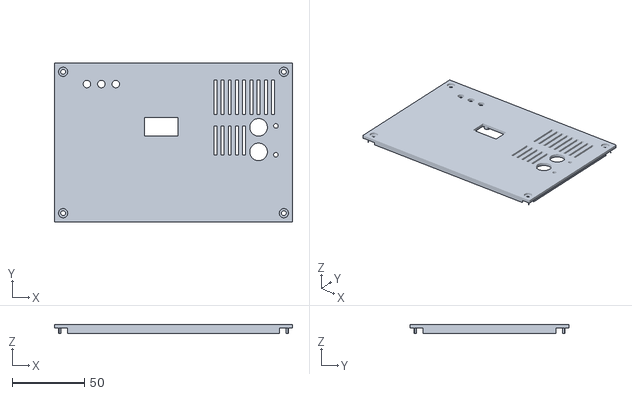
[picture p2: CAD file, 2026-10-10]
hardware/enclosure/out/gateway_lid.stl
165.0 x 110.0 x 6.50

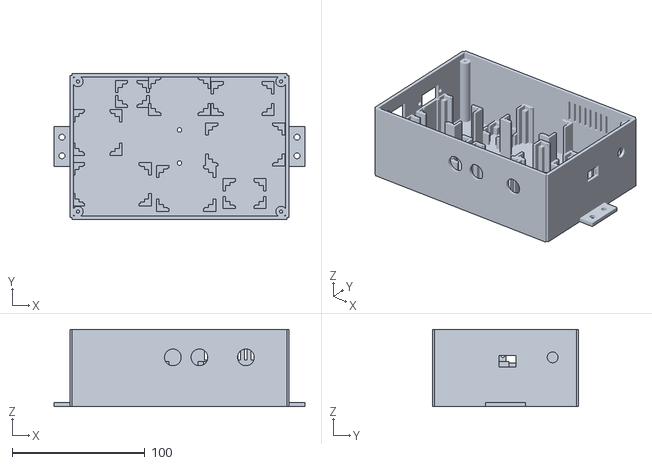
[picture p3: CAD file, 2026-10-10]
hardware/enclosure/out/gateway_base.stl
189.0 x 110.0 x 58.0

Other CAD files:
hardware/enclosure/out/gateway_lid_print.stl

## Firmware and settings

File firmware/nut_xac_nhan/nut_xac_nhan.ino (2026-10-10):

// nut_xac_nhan.ino — 2 nút OK/NG và đèn báo trên hộp gateway, để công nhân xác nhận cảnh báo AI
// mà không cần điện thoại hay đồ đo: kiểm chi tiết bằng cách quen thuộc ở chuyền rồi bấm một nút.
//
//   Nút NG (đỏ)  = "Đúng là lỗi"  — áp cho cảnh báo đang mở gần nhất (trong 15 phút).
//                  Không có cảnh báo nào mở → ghi "AI bỏ sót" cho chu kỳ vừa chạy.
//   Nút OK (xanh)= "Báo nhầm"     — áp cho cảnh báo đang mở gần nhất.
//   Đèn: xanh = bình thường · vàng = đang học / chờ duyệt / đang kiểm tra mẫu NG · đỏ nháy = có cảnh báo AI chưa xác nhận
//        đỏ sáng liền = mất kết nối PLC. Bấm nút → đèn nháy 2 lần nếu gateway đã ghi nhận, nháy nhanh 6 lần nếu lỗi.
//
// Giao tiếp qua cáp USB (Serial 115200) với tools/nut_bam_bridge.py trên laptop:
//   ESP32 → laptop:  "BTN,NG"  |  "BTN,OK"
//   laptop → ESP32:  "ANDON,<green|yellow|red|off>,<0|1 nháy>"   |   "ACK,<1|0>"
// Khi có switch và gửi MQTT thẳng qua W5500: thay Serial bằng publish gw/01/m/M01/button {"label":"fault"} và
// subscribe gw/01/m/M01/andon, gw/01/m/M01/button_ack — phần nút và đèn giữ nguyên.
//
// Gộp vào gateway_serial.ino: gọi nutSetup() trong setup() và nutLoop() trong loop(); dòng "BTN,..." không
// trùng định dạng dòng "S,..." nên laptop tách được.
//
// CHÂN (đổi nếu trùng với sơ đồ mạch thật — W5500 dùng 5/18/19/23/26, OLED và cảm biến I2C dùng 21/22):
//   Nút NG → GPIO32, nút OK → GPIO33 (nối xuống GND, dùng điện trở kéo lên trong ESP32)
//   LED đỏ → GPIO25, LED xanh → GPIO27 (qua điện trở 330 Ω). Vàng = bật cả hai (LED 2 màu) hoặc thêm LED vàng.
//   Còi (tuỳ chọn) → GPIO14
// Chưa nạp thử trên phần cứng thật.

const int PIN_NG = 32, PIN_OK = 33, PIN_RED = 25, PIN_GREEN = 27, PIN_BUZ = 14;
const unsigned long DEBOUNCE_MS = 30, LOCKOUT_MS = 800;   // chống dội phím, chống bấm đúp

String andonColor = "yellow";
bool andonBlink = false;
int ackFlashes = 0;               // số lần nháy xác nhận còn lại
unsigned long ackT = 0, ackPeriod = 150;
String rx;

struct Btn { int pin; const char* msg; bool last; unsigned long t; unsigned long fired; };
Btn btns[2] = { {PIN_NG, "BTN,NG", true, 0, 0}, {PIN_OK, "BTN,OK", true, 0, 0} };

void setLeds(bool red, bool green) {
  digitalWrite(PIN_RED, red ? HIGH : LOW);
  digitalWrite(PIN_GREEN, green ? HIGH : LOW);
}

void showAndon(unsigned long now) {
  if (ackFlashes > 0) {                         // đang nháy xác nhận sau khi bấm nút
    if (now - ackT >= ackPeriod) { ackT = now; ackFlashes--; }
    bool on = ackFlashes % 2;
    setLeds(on, on);
    return;
  }
  bool phase = !andonBlink || ((now / 400) % 2 == 0);
  if (andonColor == "green")       setLeds(false, phase);
  else if (andonColor == "yellow") setLeds(phase, phase);
  else if (andonColor == "red")    setLeds(phase, false);
  else                             setLeds(false, false);
}

void handleLine(const String& l) {
  if (l.startsWith("ANDON,")) {
    int c = l.indexOf(',', 6);
    andonColor = c > 0 ? l.substring(6, c) : l.substring(6);
    andonBlink = c > 0 && l.substring(c + 1).toInt() == 1;
  } else if (l.startsWith("ACK,")) {
    bool ok = l.substring(4).toInt() == 1;
    ackFlashes = ok ? 4 : 12;  ackPeriod = ok ? 150 : 60;  ackT = millis();
    if (!ok) { tone(PIN_BUZ, 2000, 300); }
  }
}

void nutSetup() {
  pinMode(PIN_NG, INPUT_PULLUP);
  pinMode(PIN_OK, INPUT_PULLUP);
  pinMode(PIN_RED, OUTPUT);
  pinMode(PIN_GREEN, OUTPUT);
  pinMode(PIN_BUZ, OUTPUT);
}

void nutLoop() {
  unsigned long now = millis();
  for (auto& b : btns) {
    bool v = digitalRead(b.pin);                  // LOW = đang bấm
    if (v != b.last) { b.last = v; b.t = now; }
    if (!v && now - b.t >= DEBOUNCE_MS && now - b.fired >= LOCKOUT_MS && b.t > b.fired) {
      b.fired = now;
      Serial.println(b.msg);
      tone(PIN_BUZ, 3000, 40);                    // tiếng bíp ngắn: đã bấm
    }
  }
  while (Serial.available()) {
    char ch = Serial.read();
    if (ch == '\n') { rx.trim(); if (rx.length()) handleLine(rx); rx = ""; }
    else if (rx.length() < 64) rx += ch;
  }
  showAndon(now);
}

void setup() {
  Serial.begin(115200);
  nutSetup();
}

void loop() {
  nutLoop();
}

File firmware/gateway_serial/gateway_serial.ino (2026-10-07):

// gateway_serial.ino — ESP32 + W5500 đọc PLC Mitsubishi rồi gửi số liệu lên laptop qua cáp USB.
// Dùng khi CHƯA có switch:
//
//   PLC ══ cáp mạng ══ W5500 ── ESP32 ── cáp USB ── Laptop chạy tools/plc_to_mqtt.py --serial COMx
//
// Mỗi lần đọc in một dòng:   S,<millis>,<D100>,<D102>,<D110>,<M0..M15>
// Script trên laptop cắt chu kỳ theo cờ M3, nội suy, tính đặc trưng và đẩy lên MQTT cho dashboard.
//
// Khi có switch: thay phần in ra Serial bằng gửi MQTT qua W5500 — phần đọc PLC giữ nguyên.
//
// Đọc nhanh nhất có thể, mục tiêu 100 lần/giây. Đạt được bao nhiêu phụ thuộc thời gian quét
// của PLC — không sao, laptop nội suy theo dấu thời gian thật.
// CHỈ ĐỌC — không có lệnh ghi nào vào PLC.
// Khung lệnh đã so từng byte với thư viện pymcprotocol. Chưa chạy thử trên phần cứng thật.

#include <SPI.h>
#include <Ethernet.h>

byte      MAC[]    = { 0xDE, 0xAD, 0xBE, 0xEF, 0x00, 0x50 };
IPAddress MY_IP(192, 168, 10, 50);
IPAddress PLC_IP(192, 168, 10, 21);
const uint16_t PLC_PORT = 5000;
const int W5500_CS = 5, W5500_RST = 26;
const uint8_t DEV_D = 0xA8, DEV_M = 0x90;
const unsigned long PERIOD_MS = 10;          // mục tiêu 100 lần/giây

EthernetClient plc;

size_t buildReadFrame(uint8_t* f, uint32_t devNo, uint8_t devCode, uint16_t points) {
  size_t i = 0;
  f[i++] = 0x50; f[i++] = 0x00;
  f[i++] = 0x00; f[i++] = 0xFF;
  f[i++] = 0xFF; f[i++] = 0x03; f[i++] = 0x00;
  f[i++] = 0x0C; f[i++] = 0x00;
  f[i++] = 0x04; f[i++] = 0x00;
  f[i++] = 0x01; f[i++] = 0x04;
  f[i++] = 0x00; f[i++] = 0x00;
  f[i++] = devNo & 0xFF; f[i++] = (devNo >> 8) & 0xFF; f[i++] = (devNo >> 16) & 0xFF;
  f[i++] = devCode;
  f[i++] = points & 0xFF; f[i++] = (points >> 8) & 0xFF;
  return i;
}

bool mcReadWords(uint32_t devNo, uint8_t devCode, uint16_t points, uint16_t* out) {
  if (!plc.connected() && !plc.connect(PLC_IP, PLC_PORT)) return false;
  uint8_t req[21];
  plc.write(req, buildReadFrame(req, devNo, devCode, points));

  const size_t expected = 11 + 2 * points;
  uint8_t resp[11 + 2 * 16];
  if (expected > sizeof(resp)) return false;
  size_t got = 0;
  unsigned long t0 = millis();
  while (got < expected && millis() - t0 < 500) {
    while (plc.available() && got < expected) resp[got++] = plc.read();
  }
  if (got < expected) { plc.stop(); return false; }
  if ((resp[9] | (resp[10] << 8)) != 0) return false;      // PLC báo lỗi
  for (uint16_t k = 0; k < points; k++) out[k] = resp[11 + 2 * k] | (resp[12 + 2 * k] << 8);
  return true;
}

void setup() {
  Serial.begin(115200);
  delay(300);
  pinMode(W5500_RST, OUTPUT);
  digitalWrite(W5500_RST, LOW); delay(50); digitalWrite(W5500_RST, HIGH); delay(200);
  Ethernet.init(W5500_CS);
  Ethernet.begin(MAC, MY_IP);
  delay(1000);
  if (Ethernet.hardwareStatus() == EthernetNoHardware) Serial.println("! Khong thay W5500");
  if (Ethernet.linkStatus() == LinkOFF) Serial.println("! Chua co ket noi mang toi PLC");
}

void loop() {
  static unsigned long next = millis();
  uint16_t d[11], m;
  // D100..D110 trong một lệnh, M0..M15 trong một lệnh
  if (mcReadWords(100, DEV_D, 11, d) && mcReadWords(0, DEV_M, 1, &m)) {
    Serial.printf("S,%lu,%u,%u,%u,%u\n", millis(), d[0], d[2], d[10], m);
  } else {
    Serial.println("! Doc PLC that bai — kiem tra IP, cong, Open Setting");
    delay(500);
  }
  next += PERIOD_MS;
  long wait = (long)(next - millis());
  if (wait > 0) delay(wait); else next = millis();
}

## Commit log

2026-09-20 Smart PLC Gateway - DENSO Factory Hacks 2026 (de D1)
2026-10-07 Them firmware ESP32, tools doc PLC (MC protocol), train_from_csv, QR deep-link
    Claude-Session: https://claude.ai/code/session_01DnbEUB4z8Hvnnk7UBpJFqQ
2026-10-10 docs: hướng dẫn mở lại dashboard và nối chuỗi PLC-MQTT
    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
2026-10-10 Kiểm chứng AI trên dữ liệu siết bu-lông thật (PyScrew) và phát lại qua PLC
    - ml/benchmark_pyscrew.py: train trên lần siết OK, đánh giá trên lỗi thật, xuất mô hình + file phát lại
    - tools/phat_lai_vao_plc.py: ghi chu kỳ vào D100/D102/M0 của PLC qua MC protocol
    - tools/danh_gia_qua_plc.py: chấm AI sau khi dữ liệu đi qua PLC + gateway
    - plc_gia_lap.py: hỗ trợ lệnh ghi 0x1401 và chế độ --passive
    - plc_to_mqtt.py: --model, ghi tag (D102) và điểm vào log
    - docs/HuongDan_ChungMinh_AI_PyScrew.md
    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
2026-10-10 Train và kiểm chứng trên dữ liệu máy phay CNC thật của Bosch
    - ml/benchmark_bosch_cnc.py: mỗi máy × nguyên công một mô hình, train trên lần chạy good sớm nhất,
    kiểm tra trên lần chạy good muộn hơn và 70 lần lỗi thật; so Mahalanobis với MAD, ba ngưỡng lấy từ tập train
    - ml/reports/bosch_cnc.md: kết quả thật, kể cả phần yếu
    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
2026-10-10 benchmark_pyscrew: lấy cả gradient — pyscrew 1.2.2 báo KeyError nếu bỏ
    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
2026-10-10 danh_gia_qua_plc: không tính chu kỳ chưa phát khi dùng --limit
    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
2026-10-10 Vỏ hộp in 3D cho gateway: đế, nắp, trình xem 3D
    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
    [gateway_base.stl, gateway_lid.stl, gateway_lid_print.stl]
2026-10-10 Vỏ hộp v0.2: mô hình module theo kích thước thật, lỗ nút EN/BOOT, OLED 27×27
    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
    [gateway_lid.stl, gateway_lid_print.stl]
2026-10-10 Vỏ hộp: thay HW-500 bằng HW-685 (4–20 mA → áp, 42×25), dời MPU6050
    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
    [gateway_base.stl]
2026-10-10 Vỏ hộp v0.3: chừa chỗ đầu dupont (kê cao 28 mm cho header hướng xuống), hộp cao 55 mm
    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
    [gateway_base.stl]
2026-10-10 AI tự học tại chỗ: runtime edge nhiều máy, vòng đời học→duyệt→giám sát, phản hồi, phiên bản, dashboard
    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
2026-10-10 Thêm package-lock.json để cài đúng phiên bản thư viện giao diện
    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
2026-10-10 Dashboard đổi theo loại máy (CNC, ép, siết, hàn, ép phun, khí nén), máy CNC mô phỏng, phân loại lỗi dùng chung giữa máy cùng loại
    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
2026-10-10 Giao diện kiểu MEXA: thanh bên, thanh trên có chuông thông báo, thẻ chỉ số, màu xanh chủ đạo
    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
2026-10-10 Chạy bộ phát hiện của gateway trên dữ liệu thật Bosch CNC theo cách sản phẩm sẽ chạy (học không nhãn, theo thời gian)
    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
2026-10-10 AI chính xác hơn: 3 đặc trưng chống nhiễu, học lại theo phản hồi báo nhầm; bộ đánh giá độ tin cậy có baseline và khoảng tin cậy
    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
2026-10-10 Kiểm chứng tại nhà máy: độ chính xác thực tế, AI bỏ sót, mẫu NG đầu ca, nút OK/NG + đèn trên hộp gateway; trang Kiểm chứng AI
    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
    [gateway_lid.stl, gateway_lid_print.stl]
